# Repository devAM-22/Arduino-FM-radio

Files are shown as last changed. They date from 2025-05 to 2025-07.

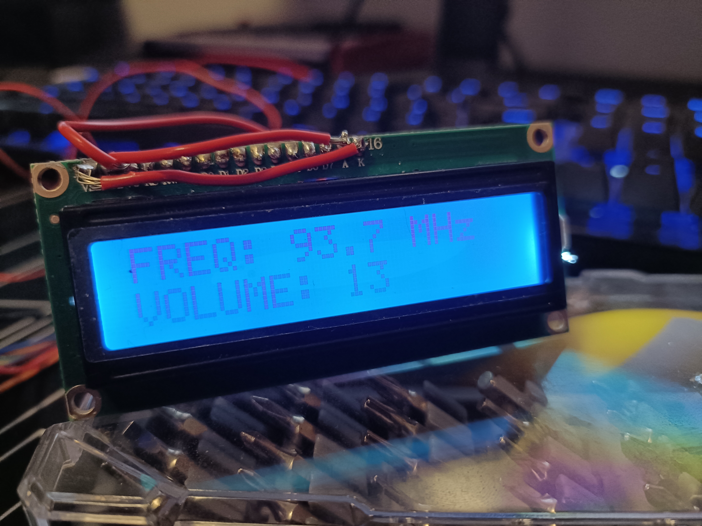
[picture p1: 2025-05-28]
Kuvat/IMG20250411095131.jpg

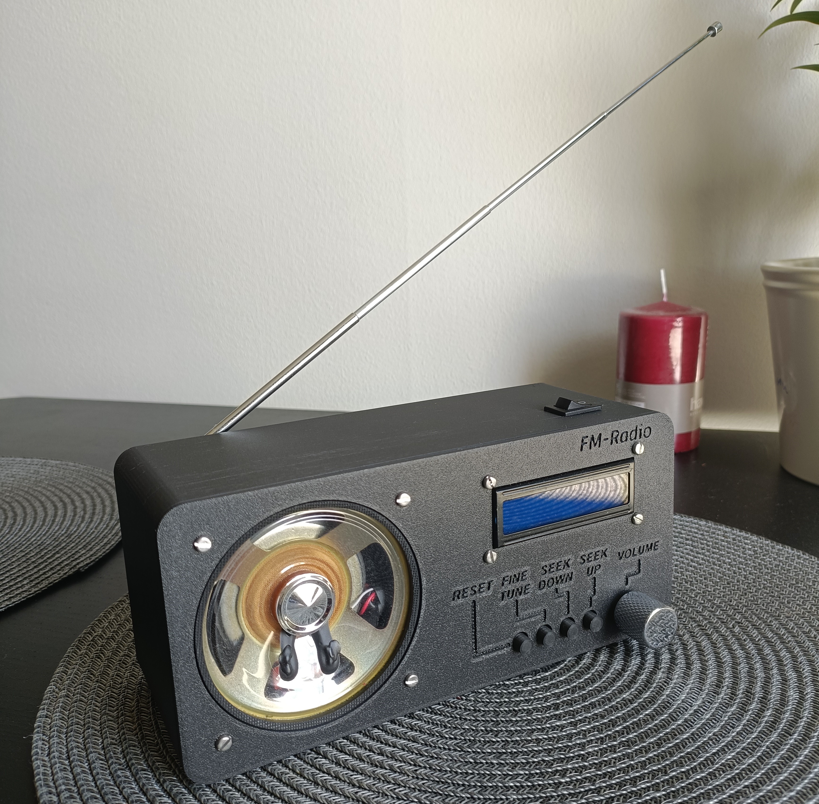
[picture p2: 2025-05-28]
Kuvat/IMG20250505140647.jpg

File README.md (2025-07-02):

\# Kandidaatintyö: Arduino-alustan hyödyntäminen elektroniikkalaitteen suunnittelussa

Tämä GitHub-repositorio sisältää kandidaatintyöni, jonka aiheena on Arduino-alustan hyödyntäminen elektroniikkalaitteen suunnittelussa. Työ on tehty osana Tampereen yliopiston tieto- ja sähkötekniikan kandidaattiohjelmaa, ja se on hyväksytty 22.5.2025.

---

\## 📁 Sisältö

\- `3D-tulostus/` – Sisältää 3D-mallin, jonka avulla laitteen kotelo on luotu  

\- `Kuvat/` – Sisältää kuvia laitteen rakentamisen eri työvaiheista  

\- `Ohjelma/` – Sisältää laitteeseen luodun pääohjelman sekä SparkFun Electronicsin Si4703\_breakout-kirjaston  

\- `Piirilevy/` – Sisältää Altium Designerilla luodut osasijoittelukuvat sekä piirilevyn valotusmaskin  

\- `Kandidaatintyö.pdf` – Valmis raportti  

\- `Lohkokaavio.png` – Lohkokaavio, joka esittää laitteen funktionaaliset lohkot  

\- `README.md` – Tämä tiedosto

---

\## 🛠️ Käytetyt teknologiat

\- Piirilevysuunnittelu: Altium Designer  

\- 3D-malli: Autodesk Fusion  

\- Ohjelmointi: Arduino IDE / C++  

\- Simulointi: LTSpice

---

\## 📨 Yhteystiedot

Aapo Manni  

📧 manni.aapo@gmail.com

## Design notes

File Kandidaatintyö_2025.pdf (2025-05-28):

## Aapo Manni

# ARDUINO-ALUSTAN HYÖDYNTÄMINEN ELEKTRONIIKKALAITTEEN SUUNNITTELUSSA

Kandidaatintyö
Informaatioteknologian ja viestinnän tiedekunta (ITC) Tarkastaja: Katja Laine
toukokuu 2025

i

## TIIVISTELMÄ

Aapo Manni: Arduino-alustan hyödyntäminen elektroniikkalaitteen suunnittelussa (Utilizing the Arduino platform in desinging of an electronic device)
Kandidaatintyö
Tampereen yliopisto
Tieto- ja sähkötekniikan kandidaattiohjelma
Toukokuu 2025

Arduinojen suosio elektroniikkalaitteiden rakentamisessa on saavuttanut suurta suosiota viimeisen kymmenen vuoden aikana. Syynä tälle suosiolle on niiden halpa hinta ja aloittelijaystävällisyys. Suosion kasvua on kiihdyttänyt myös niiden avoimen lähdekoodin saavutettavuus, jonka ansiosta Arduinon piirikaaviot, sekä muut resurssit ovat kaikkien saatavilla.
Tässä kandidaatintyössä suunnitellaan, simuloidaan ja rakennetaan Arduino-pohjainen FM-radio, joka hyödyntää mikrokontrollerinaan Arduinosta tuttua Atmega328p:tä. Samalla Arduinoa käytetään laitteen testaamiseen koekytkentälevyillä, sekä lopullisen kokoonpanon ohjelmointiin. Tässä työssä Arduinoa siis käytetään melkein jokaisessa suunnittelun vaiheessa.
Tämä työ pyrkii vastaamaan kysymykseen siitä, voiko Arduinolla itse rakentaa toimivan FM-radion. Samalla perehdytään siihen, miten Arduinoa voidaan hyödyntää elektroniikkalaitteen suunnittelun eri vaiheessa sekä siihen, että voiko itse tehdyllä radiolla rahallisesti kilpailla kaupallista tuotetta vastaan.
Rakennettu laite osoittautuu toimivaksi, mutta samalla sen toimintaa parantavia kehityskohteita on yhä havaittavissa. Lopulta päädytään tulokseen, että kaupallinen radio on käytännöllisempi ja kustannustehokkaampi valinta, mikäli käyttäjä tarvitsee yksinkertaisen vaihtoehdon radiotaajuuksien kuunteluun. FM-radiota itse suunniteltaessa on kuitenkin mahdollista vaikuttaa laajemmin luodun laitteen ominaisuuksiin. Lopuksi todetaan, että Arduino-alusta on tehokas ja edullinen tapa suunnitella elektroniikkalaitteita, koska sitä on mahdollista käyttää lähes jokaisessa suunnittelun vaiheessa aina prototyypin rakentamisesta mikrokontrollerin ohjelmointiin asti.

Avainsanat: Arduino, FM-radio, elektroniikkalaitteen suunnittelu, sulautettu järjestelmä, mikrokontrolleri, C++-ohjelmointi

Tämän julkaisun alkuperäisyys on tarkastettu Turnitin Originality Check -ohjelmalla.

ii

## TEKOÄLYN KÄYTTÖ OPINNÄYTTEESSÄ

Opinnäytteessäni on käytetty tekoälysovelluksia:

☐ Ei
☒ Kyllä

Ilmoitukseni mukaan olen käyttänyt opinnäytteessäni tutkielmaprosessin aikana seuraavia tekoälysovelluksia: ChatGPT, Andor Tekoälyavustaja

Tekoälysovellusten nimet ja versiot: GPT-4o, GPT-4, GPT-4o mini

Käyttötarkoitus: Osittainen käsitteiden suomennos, lauserakenteiden parannus, ohjelmakoodin syntaksin tarkistus sekä avustaminen lyhenneluettelon muodostamisessa. Lisäksi tiedonhaussa on käytetty Andorin Tekoälyavustajaa lähteiden etsintään.

Osiot, joissa tekoälyä on käytetty: Lyhenneluettelo, luvut 2 ja 3, lähteet ja liite D

Olen tietoinen siitä, että olen täysin vastuussa koko opinnäytteeni sisällöstä, mukaan lukien osat, joissa on hyödynnetty tekoälyä, ja hyväksyn vastuun mahdollisista eettisten ohjeiden rikkomuksista.

iii

## SISÄLLYSLUETTELO

iv

## LYHENTEET JA MERKINNÄT

3D | engl. Three-dimensional, kolmiulotteinen
AC | engl. Alternating Current, vaihtovirta
ACK | engl. Acknowledgement, tiedonsiirron vahvistus
ADC | engl. Analog to Digital Conversion, analogisen signaalin
| muuntaminen digitaaliseksi
AVR | engl. Alf and Vegard’s RISC processor, Atmelin
| mikrokontrolleriarkkitehtuuri
BOD | engl. Brown-Out Detector, jännitteen alaraja,
| jolla mikrokontrolleri resetoituu
C++ | Ohjelmointikieli
DC | engl. Direct Current, tasavirta
DIP28 | engl. Dual In-line Package, 28-pinninen kotelointi
FM | engl. Frequency Modulation, taajuusmodulaatio
GPIO | engl. General Purpose Input/Output, yleiskäyttöiset tulo-/lähtöpinnit
I2C | engl. Inter-Integrated Circuit, sarjamuotoinen
| tietoliikenneväylä mikropiirien välillä
IC | engl. Integrated Circuit, integroitu piiri
IDE | engl. Integrated Development Environment,
| integroitu kehitysympäristö
ISP | engl. In-System Programming, mikrokontrollerin
| ohjelmointi sen ollessa osa valmista piiriä
LCD | engl. Liquid Crystal Display, nestekidenäyttö
MPX | engl. Stereo Multiplexing, stereon ja monon
| yhdistäminen FM-signaalissa
PCB | engl. Printed Circuit Board, piirilevy
ppm | engl. Parts Per Million, miljoonasosa
RC | engl. Resistor-Capacitor, vastuksesta ja kondensaattorista
| koostuva oskillaattori
RDS | engl. Radio Data System, radiotietojärjestelmä
RST | engl. Reset, resetointipinni
R/W | engl. Read/Write, lukeminen/kirjoittaminen tiedonsiirrossa
SCL | engl. Serial Clock, kellosignaali
SDA | engl. Serial Data, sarjadata
SEN | engl. Serial Enable, kolmijohtoyhteyden käyttömahdollisuus
C | kapasitanssi
dB | desibeli
f−3dB | -3 dB-rajataajuus, taajuus, jossa amplitudi on laskenut kolme desibeliä
Hz | hertsi, taajuuden yksikkö
IG | maajohtimen virta
Iin | tulovirta
IL | kuormavirta

v

kHz | kilohertsi, taajuuden yksikkö
kΩ | kilo-ohmi, resistanssin yksikkö
mA | milliampeeri, virran yksikkö
MHz | megahertsi, taajuuden yksikkö
mil | piirilevysuunnittelussa käytetty mittayksikkö, 0,0254 mm
mm | millimetri
nH | nanohenry, induktanssin yksikkö
PD | regulaattorin tehohäviö
R | resistanssi
Vin | tulojännite
Vout | lähtöjännite
W | watti, tehon yksikkö
µF | mikrofaradi, kapasitanssin yksikkö

## 1. JOHDANTO

Ostettuani Arduino-aloituspakkauksen elektroniikkaharrastustani varten, havahduin poh-

timaan, mitä kaikkea kyseisellä pakkauksella voisi luoda. Olen vuosien ajan ollut äärim-

mäisen kiinnostunut langattomasta tiedonsiirrosta ja etenkin FM-radioista, mikä herätti

kysymyksen siitä, voiko Arduinon kaltaisella laitteella luoda itse kotiolossa toimivan FM-

radion. Runsaan internetin selaamisen jälkeen löysin Arduinoon kytkettävän kehitysalus-

tan, joka mahdollistaisi sen muuttamisen FM-radioksi. Päädyin lopulta ostamaan tämän

kehitysalustan, jonka jälkeen aloin toteuttamaan ensimmäistä alusta loppuun suunnitte-

lemaani elektroniikkalaitetta.

Tässä työssä suunnitellaan ja toteutetaan Arduino-pohjainen FM-radio prototyyppita-

solta valmiiksi laitteeksi asti. Luvussa 2 esitellään projektin osat yksitellen ja niiden mer-

kitystä laitteen toiminnan kannalta avataan tarkemmin. Lisäksi tässä luvussa määritel-

lään muutamia laskukaavoja, joita käytetään työn muissa vaiheissa.

Luvussa 3 siirrytään käsittelemään suunnittelun vaiheita laitteen ominaisuuksien määrit-

telystä aina viimeistellyn kotelon luontiin. Lisäksi kolmannessa luvussa testataan suun-

niteltuja lohkoja simulaatioiden avulla. Simulaatioiden jälkeen siirrytään kirjoittamaan lait-

teen ohjelmistoa, joka lopulta testataan koekytkentälevyjen avulla. Onnistuneiden tes-

tausten jälkeen suunnitellaan laitteelle piirilevy sekä ohjelmoidaan työhön tuleva mikro-

kontrolleri käyttäen Arduinoa ohjelmointityökaluna. Lopulta työ päätetään rakentamalla

3D-tulostettu kotelo laitteen elektroniikkaosien suojaksi.

FM-radio on keksintönä hyvin vanha ja monelle varsin arkinen laite. Radioita on markki-

noilla nykyään suuri määrä ja niiden ominaisuudet vaihtelevat erittäin paljon. Tämän työn

tavoitteena on vastata kysymykseen siitä, voiko itse suunniteltu radio vastata kaupasta

ostettavaa laitetta. Samalla pyritään Arduino-alustaa käyttämään mahdollisimman mo-

nessa suunnittelun vaiheessa.

## 2. PROJEKTIN OSIEN ESITTELY

Ennen projektin aloittamista on tärkeää käydä läpi sen funktionaaliset lohkot. Elektroniik-

kalaitteen suunnittelussa kannattaa laitteen osiin suhtautua itsenäisinä lohkoinaan, jol-

loin suunnittelu on helpompi jakaa osiin. Tässä kappaleessa esitetään viimeistellyn lait-

teen rakentamiseen tarvitut osat, sekä perehdytään teoriatasolla niiden merkitykseen

laitteen toiminnan kannalta.

### 2.1 Arduino

Arduino on avoimen lähdekoodin elektroniikka-alusta, mikä mahdollistaa yksinkertaisten

ja jossain tapauksessa monimutkaistenkin elektroniikkalaitteiden suunnittelun ja toteu-

tuksen. Arduino-alusta on saavuttanut suurta suosiota varsinkin opetuskäytössä sen yk-

sinkertaisuuden ja aloittelijaystävällisen käyttöliittymän vuoksi. [1] Samalla Arduino kui-

tenkin tarjoaa paljon mahdollisuuksia kokeneemmallekin elektroniikkaharrastajalle, joka

tarvitsee alustaa esimerkiksi nopean prototyypin rakentamiseen. Arduinon suurta suo-

siota on lisännyt myös se, että siihen on saatavilla suuri määrä moduuleita ja lisäosia,

joiden avulla Arduinosta itsestään on mahdollista toteuttaa esimerkiksi lämpömittari.

Näitä moduuleita ja lisäosia on mahdollista käyttää monenlaisten laitteiden prototyyppien

rakentamiseen, minkä ansiosta monet rakentavakin Arduinon ja koekytkentälevyn avulla

elektroniikkalaitteen prototyyppiversion ja siihen kuuluvan mikrokontrolleriohjelmiston

ennen varsinaisen laitteen valmistusta. Jossain tapauksessa Arduino saatetaan jopa jät-

tää osaksi viimeisteltyä laitetta.

Arduinosta on olemassa monia erilaisia malleja ja valmistajia, mutta yleisesti Arduinolla

kuitenkin viitataan Atmelin megaAVR-pohjaisen mikrokontrollerin omaaviin järjestelmiin

[2, s.77]. Pohjimmiltaan Arduino on niin kutsuttu sovituslevy (breakout board) AVR-mik-

rokontrollerille. Tämän sovituslevyn päätehtävä on luoda kiinteä pakkaus, joka helpottaa

mikrokontrollerin testausta sekä pääsyä sen eri pinneille tilanteessa, jossa komponentti

on ns. pintaliitoskomponentti [3]. Sovituslevyt ovat erittäin tärkeitä varsinkin koekytken-

tälevyllä tehtävässä testauksessa, koska pintaliitoskomponentteja ei suoraan ole mah-

dollista kytkeä koekytkentälevyn reikiin.

Useassa tilanteessa kuten tässäkin työssä, Arduinoa käytetään laitteen ensimmäisen

prototyypin rakentamiseen koekytkentälevylle ennen kuin tämä suunnitelma siirretään

PCB-levylle (Printed Circuit Board). Tämä onnistuu kopioimalla kuvassa 1 esitetty Ardui-

non arkkitehtuuri PCB-levylle käyttäen mikrokontrolleria ja siihen kytkettyjä oheislaitteita,

joista merkittävimpänä on kvartsikide, joka toimii ulkoisena kellosignaalilähteenä. Ar-

duinolla suunniteltu järjestelmä voidaan tällöin suoraan siirtää PCB-levylle.

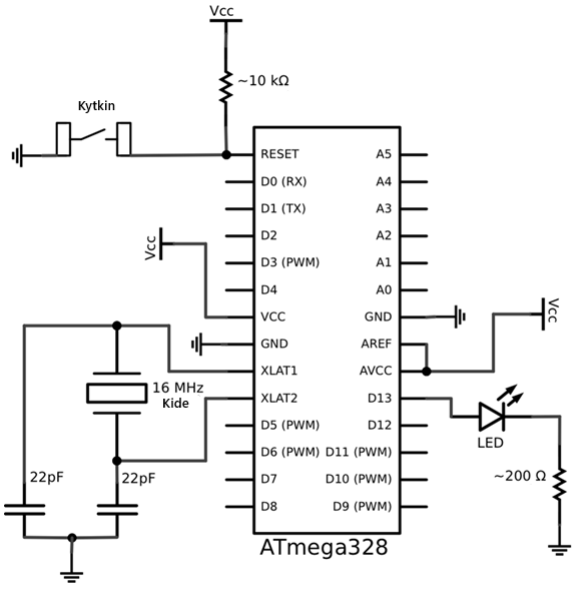
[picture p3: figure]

Kuva 1. Arduino Unon arkkitehtuuri DIP28-koteloinnille [mukaillen lähteestä 4].

Keskeinen osa sulautettua järjestelmää on sen ohjelmiston suunnittelu. Arduinon ta-

pauksessa ohjelmointi tapahtuu yleisesti Arduino IDE:n avulla. Arduino IDE on avoimen

lähdekoodin maksuton ohjelmointi- ja kehitysympäristö, joka on kehitetty juuri Arduinojen

ohjelmoimiseen [5]. Harjaantuneemmat käyttäjät siirtyvätkin useasti käyttämään kehitty-

neempiä ohjelmistoympäristöjä, kuten esimerkiksi Microchip Studiota, mitkä mahdollis-

tavat mikrokontrollerien rekisterien tarkemman tarkastelun ja monia muita kehittyneem-

piä ohjelmistotyökaluja. Arduino IDE:llä on kuitenkin omanlaisiaan etuja, joita esimerkiksi

Microchip Studiossa ei ole. Arduino IDE:n edut keskittyvät nimenomaan sen yksinkertai-

suuteen ja aloittelijaystävällisyyteen.

Käytännön ohjelmointi Arduinolla tapahtuu perinteisellä C++-ohjelmointikielellä, kuten

monissa muissakin ohjelmointiympäristöissä, mutta se kuitenkin sisältää funktioita ja ra-

kenteita, jotka yksinkertaistavat ja lyhentävät kirjoitettavaa syntaksia. Hyvänä esimerk-

kinä tällaisesta yksinkertaistuksesta on tämänkin työn kannalta tärkeä Analog to Digital

Conversion eli ADC-muunnos. ADC-muunnosta käytetään tässä työssä äänenvoimak-

kuuden lukemiseen potentiometrin jännitearvosta. Atmega328p:n datalehden mukaisesti

ADC-muunnos vaatii useita toimenpiteitä, kuten oikean ADC-kanavan valinta, ADC-

muunnoksen käyttöönotto, mahdollinen keskeytyskäsittelijä, esijakaja sekä itse muun-

noksen käynnistys [6, s. 205-220]. Arduino IDE:ssä tämä vaihe on kuitenkin luotu yh-

deksi yksinkertaiseksi funktioksi nimeltään ANALOG_READ(), jota kutsumalla Arduino

lukee parametrina annetun analogipinnin arvon ja muuntaa sen digitaaliseksi arvoksi.

Halutessaan käyttäjä voi kuitenkin kirjoittaa ohjelman käyttäen puhdasta C++-kieltä

edellä mainittujen vaiheiden mukaisesti, mutta omien funktioidensa avulla Arduino IDE

helpottaa aloittelijoiden tutustumista ohjelmointiin.

Toinen aloittelijoille suunnattu ominaisuus, jonka Arduino IDE sisältää, on sen sisäänra-

kennetut ohjelmointikirjastot. Tällaisia kirjastoja ovat esimerkiksi tässäkin työssä käytet-

tävä LiquidCrystal-kirjasto. Tämä kirjasto on suunnattu LCD-näyttöjä (Liquid Crystal

Display) varten ja se luo helpon ja yksinkertaisen tavan esittää erilaisia tietoja ohjelman

toiminnasta. Useassa tapauksessa nämä kirjastotkin on koodattu mahdollisimman käyt-

täjäystävällisiksi, siten että esimerkiksi juuri LiquidCrystal-kirjaston osalta käyttäjän tar-

vitsee vain alustaa ne Arduinon pinnit, joihin LCD-näyttö on kiinnitetty. Tämän jälkeen

käyttäjän tarvitsee vain kutsua jotain kirjaston funktiota sen enempää miettimättä, mitä

LCD-näytön toimiessa oikeastaan edes tapahtuu. Lisäksi Arduinon suuren suosion an-

siosta internetistä löytyy paljon muiden käyttäjien ja yritysten luomia kirjastoja juuri tie-

tyille Arduino-malleille, mitkä tekevät ulkoisten moduulien ja lisälaitteiden lisäämisen

vielä entistäkin helpommaksi. Tässä työssä käytettävä Si4703-kehitysalusta hyödyntää

juuri tämän tapaista kirjastoa.

Arduino on avoimen lähdekoodin sovellus, joten siitä on saatavilla kaikki tarvittavat tiedot

aina lähdekoodista piirikaavioihin asti. Tämän avoimuuden ansiosta kuka tahansa voi

siis rakentaa oman Arduinonsa, mikä on suurin syy sille, että Arduino-klooneja on saa-

tavilla runsaasti [7, luku 1]. Tässä työssä on ohjelmiston ja elektroniikkapuolen suunnit-

teluun käytetty Crowduino UNO v. 1.1:stä, joka on esitetty alla olevassa kuvassa 2. Ky-

seessä on siis Arduino UNOa vastaava klooni.

Joissakin klooneissa ominaisuudet eroavat alkuperäisestä Arduino-mallista hyvinkin pal-

jon. Tässäkin tapauksessa Crowduino UNO sisältää paljon ominaisuuksia, joita perintei-

sestä Arduino UNOsta ei löydy. Tärkein tällainen ominaisuus tämän työn kannalta on

säädettävä logiikkataso. Tämä siitä syystä, että Si4703-kehitysalusta, joka mahdollistaa

radion toiminnan, käyttää 3,3 V:n jännite- ja logiikkatasoja [8]. Perinteisessä Arduino

UNOssa käyttöjännite ja logiikkataso on asetettu olemaan aina 5 V, mikä kuitenkin pa-

himmassa tapauksessa tuhoaisi Si4703-kehitysalustan.

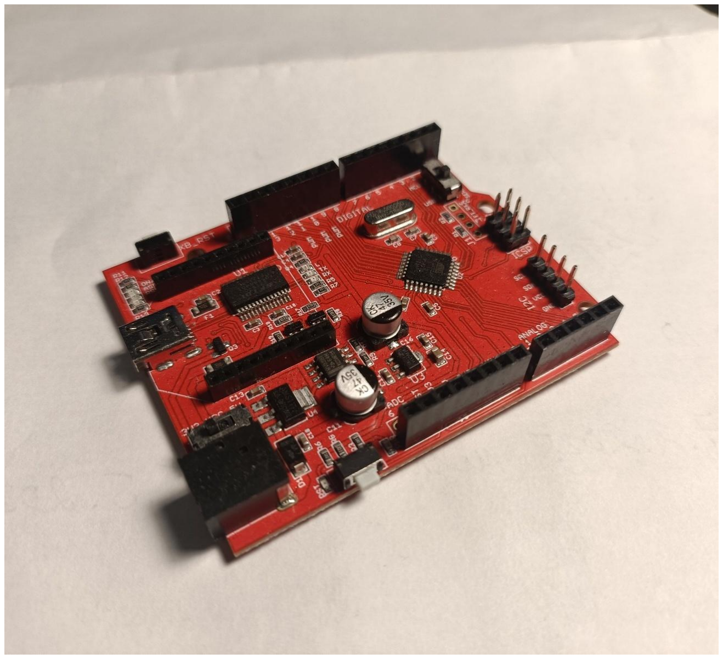
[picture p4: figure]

Kuva 2. Crowduino v1.1.

Tilanteissa, jossa Arduinolla kehitetty projekti halutaan siirtää käytännön toteutukseen

piirilevylle, tulee ottaa huomioon muutamia asioita. Näistä keskeisimpiä on käyttöjännite

ja käytetty kellotaajuus. Datalehtensä mukaisesti Atmega328p-mikrokontrolleri voi ope-

roida 2,7–5,5 V käyttöjännitteellä ja kellotaajuus voi olla välillä 0-16 MHz [6, s. 2]. At-

mega328p:n tapauksessa kellolähteeksi voidaan valita joko ulkoinen tai sisäinen kellolähde. Perinteisessä Arduino UNOssa käytetään ulkoisena kellolähteenä 16 MHz kvart-

sikidettä [4], mutta Atmega328p tarjoaa myös mahdollisuuden sisäisen RC-oskillaattorin

käyttöön kellolähteenä. RC-oskillaattoreita on Atmega328p:n tapauksessa kaksi eri-

laista, 8 MHz ja 128 kHz [6, s. 25], mitkä on mahdollista jakaa vielä pienempiin arvoihin

esijakajan avulla.

Mikäli siirtymisen Arduinolta piirilevylle haluaa tehdä mahdollisimman suoraviivaisesti,

kannattaa Arduinon arkkitehtuuri kopioida suoraan suunniteltuun laitteeseen. Toisin sa-

noen, jos projektin kehityksessä on käytetty Arduino UNOa, joka operoi 5 V:n käyttöjän-

nitteellä ja 16 MHz kellotaajuudella, kannattaa tämä arkkitehtuuri kopioida lopulliseen

kokoonpanoon, jotta siirtyminen on mahdollisimman suoraviivainen. Tämän projektin

osalta tämä siirtymä ei kuitenkaan ollut näin suoraviivainen johtuen siitä, että järjestel-

män käyttöjännite tulee olla 3,3 V. Si4703-kehitysalustan asennusohjeessa neuvotaan

käyttämään Arduino UNOn sijasta Arduino Pro Miniä järjestelmän mikrokontrollerina, jol-

loin tarvetta logiikkatasomuuntimelle ei ole [8]. Arduino UNO ja Pro Mini molemmat käyt-

tävät Atmega328p:tä mikrokontrollerinaan, mutta suurin ero niiden välillä syntyy siitä,

että Pro Mini on saatavilla myös 3,3 V:n ja 8 MHz versiona [9]. Tässä työssä Arduinon

arkkitehtuuri on siis itse asiassa kopioitu Arduino Pro Ministä, vaikka itse laitteen testaus

koekytkentälevyllä on tehty käyttäen Arduino UNOn kloonia.

Lopullisessa kokoonpanossa Atmega328p operoi siis käyttäen 3,3 V:n käyttöjännitettä.

Tämä jännitearvo asettuu hyvin datalehden mukaiseen 2,7-5,5 V:n käyttöjännitteeseen.

[6, s. 2] Kellolähteen määrittämiseen taas on useampia mahdollisuuksia. Kellolähde

määrittää siis jaksonajan, jolla mikrokontrolleri operoi. Datalehdellä esitetyn kuvaajan

(kuva 3) mukaisesti voidaan määrittää käyttöjännite ja kellotaajuus, jolla Atmega328p

operoi luotettavasti [6, s. 260]. Kuvan 3 mukaisesti 3,3 V:n käyttöjännitteellä 8 MHz kel-

lotaajuus mahdollistaa luotettavan toiminnan. Vastaavasti Arduino UNOn käyttämä kel-

lotaajuus eli 16 MHz olisi taas liian suuri käytettyyn käyttöjännitteeseen verrattuna, jolloin

mikrokontrolleri ei toimisi enää luotettavasti turvallisen käyttöalueen sisällä.

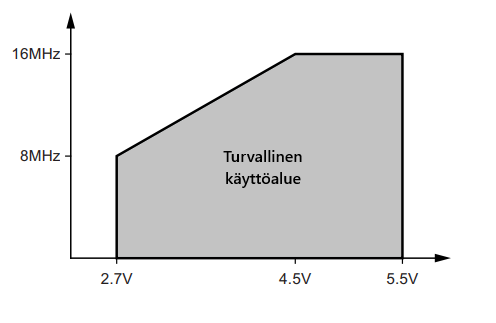
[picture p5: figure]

Kuva 3. Kellotaajuuden suuruus käyttöjännitteen funktiona [mukaillen lähteestä 6].

Edellisten päätelmien mukaisesti 8 MHz näyttäisi olevan hyvä valinta kellolähteen luo-

miseen 3,3 V:n käyttöjännitteellä. Vielä tulee kuitenkin valita, tuleeko lopullisessa projek-

tissa käyttöön ulkoinen 8 MHz kellolähde vai Atmega328p:n oma sisäinen 8 MHz oskil-

laattori. Tämän työn osalta on päädytty käyttämään ulkoista 8 MHz kvartsikidettä, koska

yleisesti niitä pidetään luotettavampina ja niiden tarkkuus on parempi kuin sisäisen os-

killaattorin. Tähän syynä on se, että ulkoisen kellolähteen, eli tässä tilanteessa kvartsi-

kiteen lupaama virhetoleranssi on ±30 ppm (Parts per million) [10]. Toisin sanoen virhettä

voi 8 MHz taajuudella syntyä maksimissaan ±240 Hz. Vastaavasti Atmega328p:n data-

lehdellä on ilmoitettu RC-oskillaattorin tarkkuudeksi huoneenlämmössä 3 V:n käyttöjän-

nitteellä ±2 % [6, s. 260]. Jos tämä arvo muunnettaisiin edelliseen tapaan taajuusarvoksi,

vastaisi se virhetoleranssia ±160 kHz. Näiden päätelmien avulla voidaan todeta, että

kvartsikiteen lisääminen kellolähteeksi on erittäin järkevää, sillä sen avulla voidaan vir-

hetoleranssia laskea moninkertaisesti. Mikrokontrollerin kellosignaalin tarkkuus tässä ti-

lanteessa on äärimmäisen tärkeä osa-alue, koska mikrokontrolleri kommunikoi Si4703-

kehitysalustan kanssa käyttäen I2C-datalinjaa (Inter-Intergrated Circuit). Ilman kunnol-

lista kellosignaalia tiedonsiirto ei onnistu tai pahimmassa tapauksessa se on virheellistä.

### 2.2 Si4703 FM-tuner

Si4703 on FM-vastaanotin IC (Integrated Circuit) erilaisiin kannettaviin sovelluksiin, ku-

ten MP3-soittimiin ja kannettaviin radioihin [11, s.1]. Tässä työssä ei kuitenkaan suora-

naisesti käytetä Si4703 IC:tä, vaan SparkFun Electronicsin valmistamaa kuvan 4 mukaista Si4703-kehitysalustaa, joka on Arduinon lailla sovituslevy Si4703 IC:lle. Tästä ke-

hitysalustasta on olemassa kahta erilaista mallia, joista toinen sisältää oman audiovah-

vistimensa ja toinen ei. Tässä työssä käytetty malli on ensimmäisenä mainittu eli se siis

sisältää jo itsessään oman audiovahvistimensa. Tämä malli on valikoitu tähän työhön

myös sen vuoksi, että se sisältää valmiiksi 3.5 mm audioliittimen, joka helpottaa laitteen

suunnittelua ja testausta koekytkentälevyllä. Tämä audioliitin mahdollistaa sen, että ke-

hitysalustaan on mahdollista kytkeä esimerkiksi nappikuulokkeet, joiden kautta voi suo-

raan kuunnella radioasemia. Käytännössä kehitysalusta hoitaa vastaanotetun FM-sig-

naalin demoduloinnin ja vahvistamisen, mutta se ei itsessään sisällä minkäänlaisia oh-

jaimia. Kehitysalustan ohjaaminen toteutetaan käyttäen I2C-sarjaliikennettä, mikä tässä

tilanteessa tehdään mikrokontrollerin avulla.

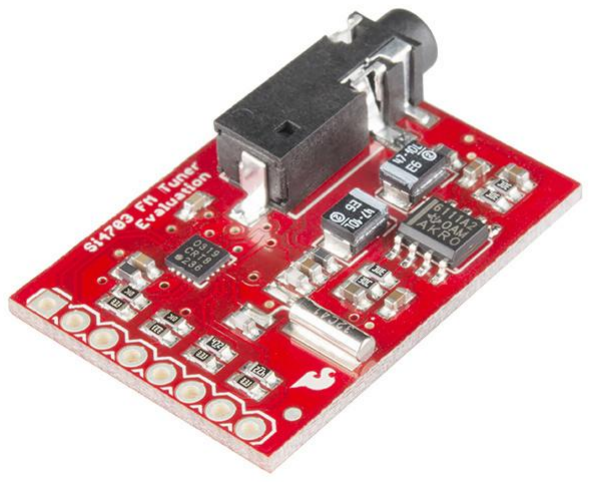
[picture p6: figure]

Kuva 4. Si4703-kehitysalusta [8].

I2C on alun perin Philipsin kehittämä sarjaliikenneprotokolla, joka on tarkoitettu mikro-

prosessorien ja niihin kytkettyjen oheislaitteiden väliseen kommunikointiin. I2C-väylä

koostuu kahdesta kaksisuuntaisesta tietolinjasta eli sarjadatalinjasta (Serial Data) ja kel-

losignaalista (Serial Clock), jotka on yhdistetty isäntälaitteen (master) ja orjalaitteen

(slave) välille. [12, s. 169] Useimmissa tilanteissa isäntälaitteena toimii juuri mikrokont-

rolleri ja orjalaitteena oheislaite, jota halutaan ohjata tai josta halutaan vastaanottaa tie-

toa. Yhteen isäntälaitteeseen on mahdollista lisätä useampi kuin yksi orjalaite kerrallaan,

koska jokaisella I2C-orjalaitteella on oma uniikki laiteosoitteensa. Tässä työssä At-

mega328p toimii I2C-väylän isäntälaitteena ja Si4703-kehitysalusta orjalaitteena.

I2C-tiedonsiirron alustuksessa isäntälaite pyrkii ottamaan yhteyden orjalaitteeseen lä-

hettämällä datalinjaan orjalaitteen laiteosoitetta ja sen perässä R/W-bittiä (read/write),

eli tietoa siitä haluaako isäntä lukea vai kirjoittaa dataa orjalaitteeseen. Mikäli laiteosoi-

tetta vastaava orjalaite löytyy, vastaa orjalaite isäntälaitteelle ACK-bitin avulla (Acknow-

ledge), jonka jälkeen itse tiedonsiirto voi alkaa. [12, s.169] Datasiirron alkaessa data

isännän ja orjan välillä alkaa siirtymään 8 bitin kehyksessä riippuen yhteyden alussa

määritetystä R/W-bitin arvosta, jonka jälkeen kehys lopetetaan orjan lähettämällä ACK-

bitillä [2, s. 95]. Mikäli R/W-bitin arvo oli yhteyden alustuksen aikana yksi, tarkoittaa tämä

sitä, että isäntä haluaa lukea dataa orjalaitteesta. Vastaavasti, jos R/W-bitti oli yhteyden

alussa nolla, haluaa isäntälaite kirjoittaa dataa orjalaitteeseen. Keskeistä I2C-kommuni-

koinissa on se, että se on toteutettu noudattamaan ns. active low-periaatetta, jolloin sig-

naalin arvo on aina korkealla, ellei sitä erikseen vedetä alas ulkoisen vastuksen avulla

arvoksi nolla. Tämä johtuu siitä, että laitteiden konfiguroinnissa on käytetty avokollekto-

ritransistoreja, jotka johtavassa tilassa vetävät datalinjan nollaan imaistessaan virtaa ul-

koisen vastuksen läpi [2, s.94-95].

Si4703-kehitysalusta sisältää käyttöjännite- ja I2C-pinnien lisäksi myös muita pinnejä

useita eri käyttötarkoituksia varten. Tällaisia pinnejä ovat SEN, RST, GPIO1 ja GPIO2.

SEN-pinni on otettu kehitysalustaan omaksi pinnikseen, sillä se mahdollistaa kommuni-

koinnin laitteen kanssa I2C:n lisäksi käyttäen kolmijohtoyhteyttä (3-Wire) [8]. Kolmijoh-

toyhteys tarkoittaa siis kokonaan eri kommunikointimenetelmää kuin I2C, koska siinä

kommunikointiin käytetään kahden johtimen sijasta kolmea. RST-pinni on nimensä mu-

kaisesti varattu kehitysalustan resetointia varten [8]. Tämän työn osalta RST-pinni on

kytketty Atmega328p:n pinniin PD2. Tämä siitä syystä, että RST-pinnillä on merkitys ke-

hitysalustan käynnistyksessä, koska sen avulla kehitysalusta asetetaan toimimaan käyt-

täen I2C-tiedonsiirtoa kolmijohtoyhteyden sijasta [11, s.19]. Erona tässä SEN-pinniin on

se, että RST-pinnin tilaa tulee vaihtaa alustuksen aikana korkean (1) ja matalan tilan (0)

välillä. SEN-pinnin kohdalla riittää johtoyhteyden valintaan joko korkea tai matala tila.

Tässä tilanteessa kehitysalustaan on lisätty valmiiksi 10 kΩ ylösvetovastus, mikä mah-

dollistaa sen [8], että SEN-pinnin signaali on vakiona aina korkea. Tästä seuraa se, että

SEN-pinniin ei tarvitse kytkeä johdinta, mikäli käyttöön halutaan ottaa I2C-kommuni-

kointi. Kehitysalustan kaksi viimeistä pinniä GPIO1 ja GPIO2 ovat yleiskäyttöisiä tulo- ja

lähtöpinnejä (General Input/Output pins), joita voidaan käyttää useaan eri tarkoitukseen

[8]. Yleisesti näitä kahta pinniä voidaan käyttää indikaattorina siitä, että onko RDS-data

(Radio Data System) valmista luettavaksi tai onko kuunneltu kanava stereo- vai mono-

kanava [11, s.16].

Eräs syy siihen, miksi juuri Si4703-kehitysalusta on valittu tähän työhön, on se, että siitä

on saatavilla valmiina oleva Arduino-kirjasto, mikä helpottaa vastaanottimen ohjaamista

huomattavasti. Toisin sanoen tämä kirjasto sisältää valmiit komennot, joilla kehitysalus-

taa ohjataan. Tämän kirjaston takana on sama tuotantoryhmä, joka on suunnitellut

Si4703-kehitysalustan eli SparkFun Electronics [13]. Arduino-kirjasto helpottaa laitteen

ohjelmointia suuresti, koska ohjelmiston puolesta suurin työ on tehty jo valmiiksi. Jos

kuitenkin kirjaston sisältöä haluaa muokata tai luoda kokonaan oman Arduino-kirjas-

tonsa Si4703:n hallintaan, on sekin täysin mahdollista. Si4703-datalehdellä on esitetty

kaikki toimenpiteet ja niitä koskevat rekisterit, joita muokkaamalla voi muokata IC:n toi-

mintaa. Tämän työn osalta Si4703-kirjasto on jätetty melko koskemattomaksi yhtä rekis-

teriä lukuun ottamatta. Tästä muutoksesta lisää luvussa 3.3.

Koska Si4703 IC on suunniteltu kannettaviin sovelluskohteisiin, on sen eräs erikoisuus

se, että se ei tarvitse ulkoista antennia vaan antennin virkaa hoitaa ulkoinen kuulokelii-

täntä. Tässä ongelmaksi muodostuu kuitenkin se, että Si4703 IC ei sisällä suoraa val-

miutta ulkoisen antennin yhdistämiseen. [14, s. 1] Koska Si4703 käyttää pääsääntöisesti

kuulokejohtoa ulkoisena antennina, on kehitysalustaan kytketty sitä varten kaksi lisä-

komponenttia, jotka mahdollistavat FM-taajuusalueen parhaan mahdollisen kuulumisen.

Näitä ovat kuvan 5 mukaisesti 270 nH käämi sekä AC-kytkentä, joka on toteutettu käyt-

täen 1 nF kondensaattoria [15]. AC-kytkennän tarkoitus on suodattaa vastaanotetusta

radiosignaalista DC-komponentti (DC-offset) [14, s. 19]. Vastaanotetun radiosignaalin

tulisi olla mahdollisimman puhdas AC-signaali, koska DC-komponentit aiheuttavat lait-

teen toimintaa haittaavia vääristymiä. Kondensaattorin lisäksi kytkennässä on 270 nH

käämi, joka pyrkii maksimoimaan jännitevahvistuksen koko FM-taajuusalueella [14,

s.19].

Kuvan 5 mukaisen käämin L1 ja kondensaattorin C5 arvo on määritetty käytettäväksi

silloin, kun antennina käytetään kuulokejohtoa. Tässä työssä tilanne on kuitenkin erilai-

nen, koska antennin tehtävää hoitaa ulkoinen piiska-antenni. Tällöin piiska-antennin koh-

dalla olisi käämin L1 ja kondensaattorin C5 arvot pitänyt määrittää uudelleen, jotta vas-

taanotettu signaali olisi ollut laadultaan paras mahdollinen. Tämän työn osalta arvojen

uudelleenmääritys on jätetty tekemättä, koska käytännön testauksen perusteella päästiin

kuuluvuuden osalta hyviin tuloksiin kytkemällä piiska-antenni suoraan kuulokeliitäntään

alla olevan kuvan 5 mukaisesti. Piiska-antenni on kytketty siis suoraan 3.5 mm audioliit-

timen maajohtimeen.

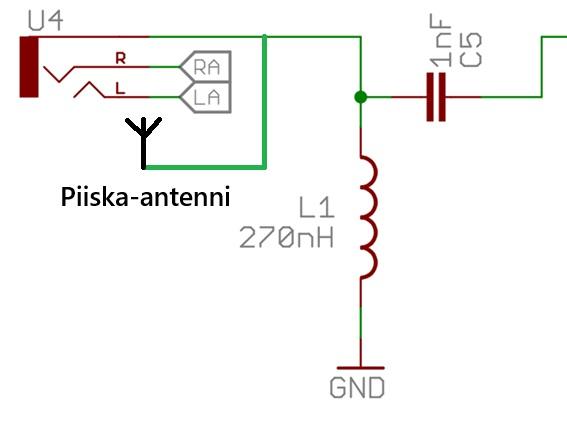
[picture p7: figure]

Kuva 5. Antenni ja sen lisäkomponentit [mukaillen lähteestä 15].

Si4703 IC:n mielenkiintoinen ominaisuus on se, että siihen on luotu valmius RDS-datan

prosessointiin. RDS on lyhenne sanoista Radio Data System, joka nimensä mukaisesti

tarjoaa mahdollisuuden radioaseman datan prosessointiin. Radioasemien lähettämä

data sisältää esimerkiksi tiedot siitä, mikä on toistettavan aseman tai soitettavan kappa-

leen nimi. [11, s.15] Tämän työn osalta RDS-datan prosessointi on jätetty pois käsitte-

lystä aihealueen rajaamiseksi. Laiteeseen on kuitenkin sisällytetty valmius RDS-datan

prosessointiin ja näin se olisi mahdollista lisätä osaksi laitetta tulevaisuudessa tekemällä

muutoksia ohjelmistoon.

### 2.3 LCD-näyttö

Radion toiminnan kannalta on äärimmäisen tärkeää, että käyttäjä saa jonkinlaista infor-

maatiota siitä, mitä kehitysalusta ja mikrokontrolleri ovat suorittamassa. Tällaista tietoa

on esimerkiksi soitossa oleva FM-taajuus sekä kanavan äänenvoimakkuus. Näiden tie-

tojen näyttämiseen tarvitaan siis jonkinlainen näyttö. Tässä työssä tähän tehtävään on

valittu LCD-näyttö.

LCD:n toiminta perustuu nimensä mukaisesti nestekiteisiin (liquid crystal), jotka on sul-

jettu kahden polarisoivan levyn väliin. Keskeistä kahdessa polarisoivassa levyssä on se,

että ne on sijoitettu 90° kulmaan toisiinsa nähden, jolloin valo voi polarisoitua vain näiden

kahden levyn polarisaatiosuunnan mukaisesti. [16, s. 43] Polarisoimattoman valon kom-

ponenteista pääsevät siis läpi vain ne, jotka ovat yhdensuuntaisia polarisoivien levyjen kanssa. Valon polarisointi mahdollistaa sen, että kun nestekidetason yli kytketään jän-

nite, kääntyvät nestekiteet sähkökentän suuntaisesti, jolloin polarisoitu valo ei pääse läpi

toisesta polarisoivasta levystä [16, s. 44]. Tällöin kyseinen pikseli esiintyy pimeänä. Vas-

taavasti, jos jännite kytketään pois päältä, pystyvät nestekiteet liikkumaan vapaasti, jol-

loin taustavalolta saapuva valo pääsee etenemään molempien polarisoivien levyjen läpi.

Tällöin kyseinen pikseli kytkeytyy päälle. Näin ollen jokaisen pikselin päällä oloa voidaan

kontrolloida yksinkertaisesti kytkemällä jännite nestekidetasoon. Ohjaamalla yksittäisiä

pikseleitä ja niiden joukkoja, voidaan muodostaa merkkejä sekä numeroita. Edellä ku-

vattu LCD-pikselin toiminta on havainnollistettu alla olevassa kuvassa 6.

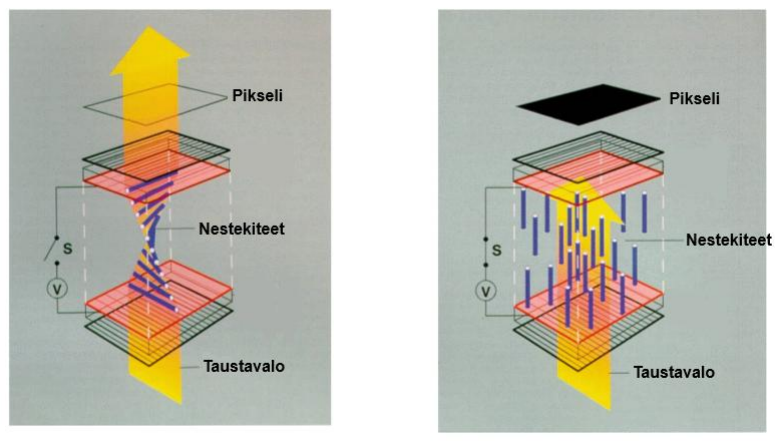
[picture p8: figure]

Kuva 6. Yksittäisen LCD-pikselin toiminta. Vasemmalla esitetty tilanne, jossa pik-

seli on päällä ja oikealla tilanne, jossa pikseli on kiinni [mukaillen lähteestä 17].

Pikseleiden ohjaukseen on monia tapoja, mutta tässä työssä ohjaus on toteutettu käyt-

täen Hitachi HD44780-ohjainpiiriä [18]. Ohjainpiirin tehtävä on siis hoitaa edellä mainittu

yksittäisten pikseleiden päälle kytkentä ja tällä tavoin mahdollistaa merkkien osoittami-

nen käyttäjälle. Ohjainpiiri on siis osa LCD-moduulia, jolloin sen ohjaaminen on mahdol-

lista kytkemällä se suoraan mikrokontrolleriin. LCD-kytkentää laitteeseen yksinkertais-

taa myös se, että samaan tapaan kuin Si4703-kehitysalustan kanssa, löytyy Hitachi

HD44780-ohjainpiiriä käyttäviin LCD-näyttöihin valmis Arduino-kirjasto nimeltään Li-

quidCrystal [18]. Si4703-kehitysalustan tavoin tämä kirjasto siis sisältää valmiit funktiot,

joiden avulla tekstin saaminen LCD-näytölle ja sitä kautta käyttäjälle onnistuu äärimmäi-

sen kätevästi.

### 2.4 Audiovahvistinkytkentä

Si4703-kehitysalusta mahdollistaa FM-taajuuksien demoduloinnin audiosignaaliksi.

Tämä audiosignaali on kuitenkin varsin heikko, jolloin se tulee vahvistaa jotenkin, jotta

se on mahdollista toistaa kaiuttimesta. Tähän tehtävään avuksi tulee audiovahvistinkyt-

kentä. Tässä työssä yksinkertainen audiovahvistin on toteutettu käyttäen LM386 IC:tä.

LM386 on matalan käyttöjännitteen audiovahvistin [19, s.1], joka siis tämän työn kohdalla

vahvistaa Si4703-kehitysalustalta tulevan audiosignaalin kaiutinta varten. Kuvassa 7 on

esitettynä tässä työssä käytetty kytkentä.

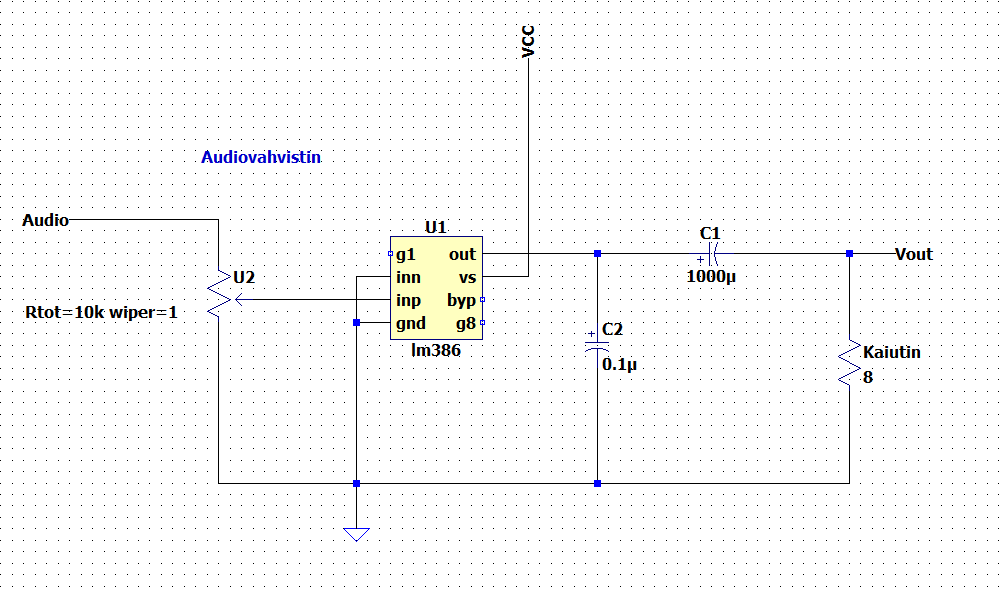
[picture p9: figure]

Kuva 7. LM386-audiovahvistinkytkentä LT Spice-ohjelmassa esitettynä.

Kuvassa 7 olevassa kytkennässä on otettu vaikutteita LM386-datalehden mallikytken-

nästä. Tällä kyseisellä kytkennällä vahvistus on 26 dB, joka tässä sovelluskohteessa

riittää mainiosti. [19 s. 10] Kytkentää on kuitenkin muokattu hieman mahdollistamaan

paras mahdollinen toiminta. Keskeisin tällainen muutos on nähtävissä kuvan 7 konden-

saattorissa C1. Datalehden mallissa tämän kondensaattorin arvoksi on määritetty 250

µF. Tämä arvo on kuitenkin aivan liian matala musiikin kuunteluun, koska tällaisessa

tilanteessa vahvistimen ulostulo toimii eräänlaisena ylipäästösuotimena. Toisin sanoen

toistettavat musiikin alimmat taajuudet määräytyvät tämän kondensaattorin mukaan ja

mikäli tämän kondensaattorin arvo on liian matala, suodattuvat matalat bassotaajuudet

pois musiikista.

Audiovahvistimen -3 dB-rajataajuus voidaan määrittää seuraavanlaisilla laskukaavoilla

1 f−3dB = 2πRC | (1)
1 C = 2πRf−3dB | (2)

, jossa R on vahvistimen kuorma eli tässä tilanteessa kaiuttimen vastus ohmeina, f−3dB

on audiovahvistimen -3 dB-rajataajuus ja C on ulostulossa olevan kondensaattorin C1

kapasitanssi [20, luku 5.8]. Koska kaiuttimen halutaan toistavan audiosignaalin taajuuk-

sia mahdollisimman laajalta alueelta, tulee kondensaattorille C1 valita mahdollisimman

suuri kapasitanssin arvo tiettyjen viitearvojen sisältä. Tässä tilanteessa nämä viitearvot

määrittää ihmisen kuuloalue.

Musiikin bassotaajuudet, joita audiovahvistimen tulee toistaa, sijoittuvat välille 20Hz-

300Hz [21, luku 1.12]. Kondensaattoria C1 määrittäessä kannattaa sen arvo valita siten,

että vahvistinpiiri itsessään ei rajoita näiden taajuuksien toistamista. Näin ollen voidaan

kaavan 2 mukaisesti laskettuna todeta, että ulostulokondensaattorin arvo tulisi olla 20

Hz:n taajuudella noin 1000 µF. Tällä ulostulokondensaattorin C1 arvolla myös alimmat

bassotaajuudet kuuluvat nyt audiovahvistimen ulostulon taajuusalueeseen. Huomioita-

vaa tässä on kuitenkin se, että datalehden mukaisella 250 µF arvolla kaiuttimen –3 dB-

rajataajuus olisi sen sijaan n. 80Hz kohdalla. Tällä kondensaattorin arvolla audiovahvis-

tin siis suodattaisi pois suuren osan musiikin alimmista bassotaajuuksista.

Muuta huomioitavaa tässä audiovahvistinkytkennässä on se, että lopullista äänenvoi-

makkuuden säätöä ei toteuteta kuvassa 7 näkyvällä säätövastuksella, vaan digitaalisesti

luodun ohjelmiston avulla. Kuvan 7 säätövastus on kuitenkin sijoitettu lopulliseen ko-

koonpanoon hienosäätöelementiksi eli sen avulla voidaan varmistaa, että ulostuleva

ääni ei säröydy, vaikka audiovahvistimeen saapuva ääni olisi suurin mahdollinen. Sää-

tövastuksen avulla voidaan siis luoda ikään kuin rajoitin, joka varmistaa suurimman mah-

dollisen äänenvoimakkuuden valinnan.

### 2.5 Regulaattorikytkentä

Käyttöjännitteen määrittely on erittäin tärkeä osa elektroniikkalaitteen suunnittelua.

Tässä tilanteessa käyttöjännitteen määrittely on melko yksinkertaista, koska Si4703-ke-

hitysalusta käyttää käyttöjännitteenään ja logiikkatasonaan 3,3 V:n jännitettä. Dataleh-

den mukaisesti Si4703-kehitysalustaa on mahdollista käyttää 5 V:n käyttöjännitteelle,

mutta moduulin logiikkatasona on tässäkin tapauksessa 3,3 V:n jännite. Mikäli kehitys-

alusta kytkettäisiin suoraan 5 V:n jännitteeseen, voisi tämä jännite pahimmassa tapauk-

sessa tuhota laitteen. Jos kehitysalustaa jostain syystä haluttaisiin käyttää 5 V:n jännit-

teellä tulisi logiikkatasojen väliin kytkeä niin sanottu logiikkatasomuunnin. [8] Tällaisen

logiikkatasomuuntimen tarve voidaan kuitenkin poistaa suunnittelemalla laite käyttä-

mään koko ajan 3,3 V:n jännitettä, koska tällaisessa tilanteessa laitteen muut osat eivät

vaadi edellä mainittua 5 V:n jännitettä. Tässä työssä laite saa jännitteensä neljältä sar-

jaan kytketyltä AA-paristolta. Tällaisen paristokytkennän napojen välinen jännite on 6 V.

Tämä jännite on kuitenkin liian suuri syötettäväksi suoraan järjestelmään, minkä vuoksi

se tulee reguloida.

Jänniteregulaation keskeisin tavoite on pitää laitteen käyttöjännite vakiona kuormavirran,

ympäristötekijöiden tai tulojännitteen muuttuessa [2, s.239-240]. Tämän työn osalta

kuormavirta pysyy suhteellisen vakiona laitteen operoidessa, mutta laitteen tulojännite ja

ympäristötekijät ovat muuttuvia parametrejä, jotka tulee huomioida suunnittelussa. Var-

sinkin laitteen tulojännite muuttuu hyvinkin paljon paristojen tyhjentyessä. Vastaavasti

ympäristötekijät muuttuvat riippuen siitä, missä lämpötilassa laitetta käytetään.

Pääsääntöisesti regulointimenetelmät jaetaan kahteen eri luokkaan riippuen siitä, onko

reguloitava kuorma rinnan- vai sarjaankytketty regulaation suorittavan säätöelementin

kanssa [23, s.300]. Nykyaikana kuitenkin yleisempi menetelmä varsinkin regulaattori

IC:den kohdalla on sarjaregulointi, jossa säätöelementti on toteutettu transistoripiirin

avulla [2, s.240]. Tässä työssä käytetty regulaattorikytkentä on lineaarinen, joka tarkoit-

taa sitä, että säätöelementti toimii lineaarisella alueella [23, s.301]. Toisin sanoen regu-

laattorin toimiessa sen käyttöalueella, muuttaa säätöelementti toimintaansa lineaarisesti

siten, että lähtöjännite pysyy vakiona kuormavirran tai tulojännitteen muuttuessa. Line-

aaristen regulaattorien negatiivisena puolena on kuitenkin tulon ja lähdön välisestä po-

tentiaalierosta syntyvät tehohäviöt ja siten alhaisempi hyötysuhde [2, s.244].

Lineaarisen regulaattorin sijasta olisi mahdollista käyttää niin kutsuttua hakkuriteholäh-

dettä (switching regulator), jonka hyötysuhde on lineaarisia regulaattoreita parempi [23,

s.323]. Hakkuriteholähteiden haittana taas on se, että ne ovat useasti rakenteeltaan monimutkaisempia [23, s.323]. Tämän edellä mainitun seikan vuoksi on tässä työssä pää-

dytty käyttämään lineaarista teholähdettä niiden yksinkertaisuuden ja halvan hinnan

vuoksi. Lisäksi potentiaaliero regulaattorin tulon ja lähdön välillä sekä kuormavirta (n. 50

mA) ovat tässä työssä niin pieniä, että merkittävää tehohäviötä ei synny, vaikka ky-

seessä onkin lineaarinen regulaattorikytkentä.

Tähän työhön valikoitunut regulaattori on lineaarinen Texas Instrumentsin valmistama

LM1117 IC, jolla luotu kytkentä on esitetty alla olevassa kuvassa 8. Tätä kyseistä regu-

laattoria valmistetaan useammalle eri jännitearvolle, mutta koska tässä tilanteessa jän-

nitteen halutaan pysyvän koko ajan 3,3 V:n arvossa, voidaan valita malli, missä jännite

on “lukittu” tähän arvoon.

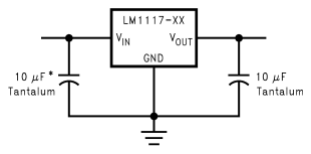
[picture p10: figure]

Kuva 8. Regulaattorikytkentä [22, s.16].

Regulaatiopiiriä suunnitellessa on kuitenkin tärkeää muistaa, että jännitteen alentami-

sesta syntyy aina tehohäviötä, joka muuttuu regulaattori IC:n kohdalla lämmöksi. Tällöin

tulojännitteen valinnassa kannattaa pyrkiä siihen, että potentiaaliero tulo- ja lähtöjännit-

teen välillä on mahdollisimman pieni. Tässä työssä kuormavirta on hyvin pieni, minkä

vuoksi LM1117 IC:n jäähdytyksestä ei tarvitse välittää. Kuitenkin jos potentiaaliero tulo-

ja lähtöjännitteen välillä olisi suurempi, voisi pienikin kuormavirta aiheuttaa IC:n merkit-

tävää lämpenemistä [2, s.242]. Joka tapauksessa kannattaa hukkatehon määrä aina mi-

nimoida. Tulon ja lähdön välinen potentiaaliero ei myöskään saa olla liian pieni, koska

tällöin regulaattori ei kykene luotettavaan toimintaan.

Regulaattorien tapauksessa tästä minimipotentiaalierosta käytetään nimitystä pudotus-

jännite (dropout voltage). LM1117:n datalehdellä on mainittu, että 100 mA kuormavirralla

tulo- ja lähtöjännitteen ero tulee olla on ainakin 1,2 V [22, s.6]. Tästä syystä työhön on

valittu jännitelähteeksi 6 V:n paristokytkentä, sillä 6 V:n jännite on tarpeeksi suuri mah-

dollistamaan regulaattorin varma toiminta, mutta samalla 6 V:n ja 3,3 V:n välinen poten-

tiaaliero on niin pieni, että merkittävää tehohäviötä ei synny.

Tämän työn simulaatio-osiota varten on tärkeää määrittää laskukaava regulaattorikyt-

kennän tehohäviölle. Ohjeet tehohäviön laskemiseen on esitetty yksityiskohtaisesti

LM1117-datalehdellä. Tältä datalehdeltä löytyvät alla esitetyt laskukaavat 3 ja 4, jotka

mahdollistavat tehohäviön laskemisen. [22, s.18]

Iin = IL + IG | (3)
PD = (Vin − Vout)IL + VinIG | (4)

Kaavassa 3 Iin on tulovirta, joka samalla Kirchoffin virtalain mukaisesti on kuormavirran

IL

ja maajohtimen virran IG summa. Kaavassa 4 PD on regulaattorin lämmöksi haihtuva

tehohäviö, Vin on tulojännite ja Vout on lähtöjännite. Lisää regulaattorikytkennän simu-

loidusta tehohäviöistä on kerrottu luvussa 3.2.

## 3. SUUNNITTELUN VAIHEET

Elektroniikkalaitteen suunnittelu kannattaa aloittaa sen ominaisuuksien määrittelystä.

Suunnittelun alkuvaiheessa kannattaa siis tarkkaan miettiä, mitä laitteen tulee pystyä

suorittamaan. Tämän työn osalta tämä vaihe on melko suoraviivainen, koska FM-radio

laitteena on monelle jo entuudestaan hyvin tuttu. Näin ollen laitteen määrittely on suu-

rimmalta osin tehty jo valmiiksi.

### 3.1 Laitteen määrittely

FM-radion keskeisin tehtävä on demoduloida ja toistaa FM-kantoaallolla välitetty viesti

eli FM-radioaseman lähettämä ohjelma. Kun vastaanotettu lähetys on saatu demoduloi-

tua, tulee tämä sisältö vahvistaa ja toistaa kuuntelijalle. FM-signaalin demoduloinnin ja

vahvistamisen suorittaa tässä työssä Si4703-kehitysalusta. Demoduloinnin jälkeen au-

diosignaali tulee saada siirrettyä kaiuttimelle käyttäjän kuunneltavaksi. Tähän tehtävään

tarvitaan siis jonkinlainen audiovahvistin sekä kaiutin, joka toistaa vastaanotetun sano-

man. Kaikissa tilanteissa audiosignaalia ei haluta toistaa samalla voimakkuudella, minkä

vuoksi äänenvoimakkuuden säätö tulee myös ottaa osaksi laitteen suunnittelua.

Äänenvoimakkuuden säätämisen lisäksi tulee soitettavaa FM-taajuutta pystyä muutta-

maan. Taajuuden vaihto tapahtuu kolmen erillisen kytkimen avulla, joiden avulla FM-

taajuusalueelta voidaan etsiä kanavia liikkuen ylös- ja alaspäin yhden desimaalin tark-

kuudella. FM-taajuuden säätö yhden desimaalin tarkkuudella on tärkeä lisä laitteeseen,

koska ylös- ja alaspäin etsittäessä Si4703-kehitysalusta etsii kanavia niiden signaalite-

hon perusteella. Tällöin on mahdollista, että kehitysalusta ohittaa joitakin kanavapaik-

koja, jos niiden signaaliteho on liian heikko. Lisäämällä laitteeseen mahdollisuuden liik-

kua FM-taajuusalueella yhden desimaalin tarkkuudella, saadaan näin katettua koko FM-

taajuusalue.

FM-taajuuden säätämisen lisäksi sisältää laite vielä neljännen kytkimen, jonka tarkoitus

on resetoida laite. Resetointi on mikrokontrollerijärjestelmissä tärkeä ominaisuus, koska

se mahdollistaa vikatilanteiden korjauksen laitteen uudelleenkäynnistyksellä. Tässä

työssä radio alkaa toistamaan ohjelmistossa määritettyä kanavaa heti käynnistyksen jäl-

keen. Tällöin jos yksittäinen kanava on asetettu ohjelmistossa käynnistymään aina lait-

teen toiminnan alkaessa, voidaan RESET-kytkimellä siirtyä kuuntelemaan tätä kanavaa.

Viimeisimpänä tarvitaan laitteeseen jonkinlainen näyttö, jotta käyttäjä pystyy seuraa-

maan laitteen toiminnan vaiheita eli toistettavaa FM-taajuutta ja äänenvoimakkuuden ta-

soa. Nämä tiedot ovat käyttäjälle äärimmäisen tärkeitä, koska ne ovat tämän työn osalta

ainoita parametreja, joita käyttäjä voi muuttaa laitteen toiminnan aikana. Kuvassa 9 on

esitetty lohkokaavio, johon on sisällytetty laitteen kaikki funktionaaliset lohkot.

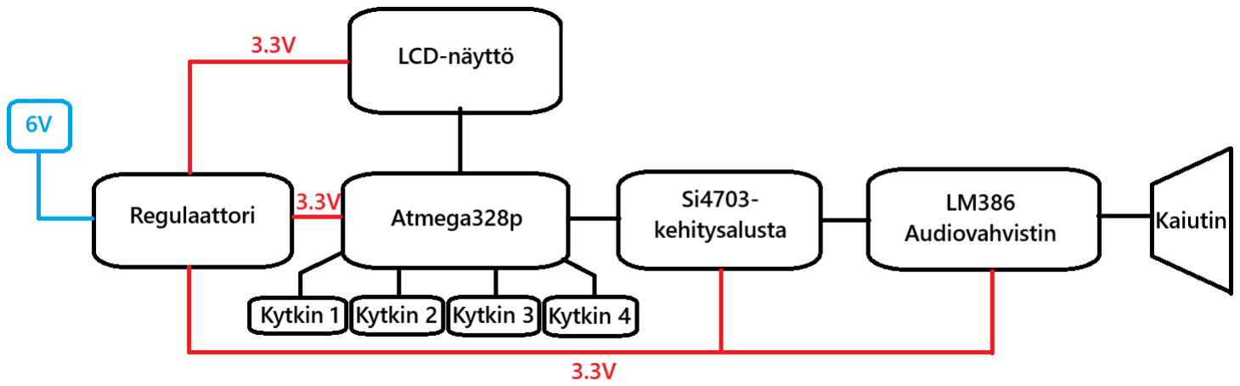
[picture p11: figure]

Kuva 9. FM-vastaanottimen lohkokaavio.

### 3.2 Osien ja lohkojen simulointi

Tämä projekti on ollut erittäin käytännönläheinen eli monia asioita on suunniteltu suoraan

koekytkentälevyllä kokeilemalla. Tämän työn osalta tällainen testaus on mahdollista,

koska käytössä olevien lohkojen osalta on ollut saatavilla runsaasti dokumentaatiota ja

ohjeita, joidenka pohjalta laitetta on ollut mahdollista rakentaa. Tämän tapaisessa tes-

tauksessa on kuitenkin riskinsä, sillä jos kytkentöihin ja ohjeistuksiin ei kiinnitä tarpeeksi

huomiota, on mahdollista että laite tai sen osia tuhoutuu.

Suurin ongelmien aiheuttaja tässä työssä on käyttöjännitteen suuruus. Ongelma muo-

dostuu siitä, että perinteinen Arduino UNO käyttää 5 V:n käyttöjännitettä ja logiikkata-

soja, kun taas tämän laitteen muut osat käyttävät 3,3 V:n käyttöjännitettä. Tätä ongelmaa

ratkaisemaan kehitettiin teoriaosuudessa kuvassa 8 esitelty regulaattorikytkentä. Ennen

laitteen lopullista rakentamista tulee kuitenkin simuloida, toimiiko tämä regulaattorikyt-

kentä odotetulla tavalla. Tällaisia simuloitavia aiheita on esimerkiksi jo teoriaosuudessa

mainittu hukkatehon määrä sekä itse regulaation onnistuminen.

Tässä työssä kaikki simulaatiot on toteutettu käyttäen LT Spice-simulaatio-ohjelmaa. Re-

gulaattoripiiriä simuloitaessa on käytetty LT Spice-ohjelman valmista komponenttia

LT1117-3.3, joka vastaa erittäin paljon työssä käytettävää LM1117-3.3 komponenttia

[24]. Lisäksi kytkennän kuormaksi on asetettu ideaalinen virtalähde, joka simuloi kytkennän koekytkentälevyltä mitattua 50 mA kuormavirtaa. Ensimmäisessä simulaatiossa tes-

tattiin komponentin regulointiominaisuuksia pyyhkäisemällä tulojännitteen arvoa välillä

0-20 V, milloin saatiin lähtöjännitteelle alla olevan kuvan 10 mukaisia tuloksia.

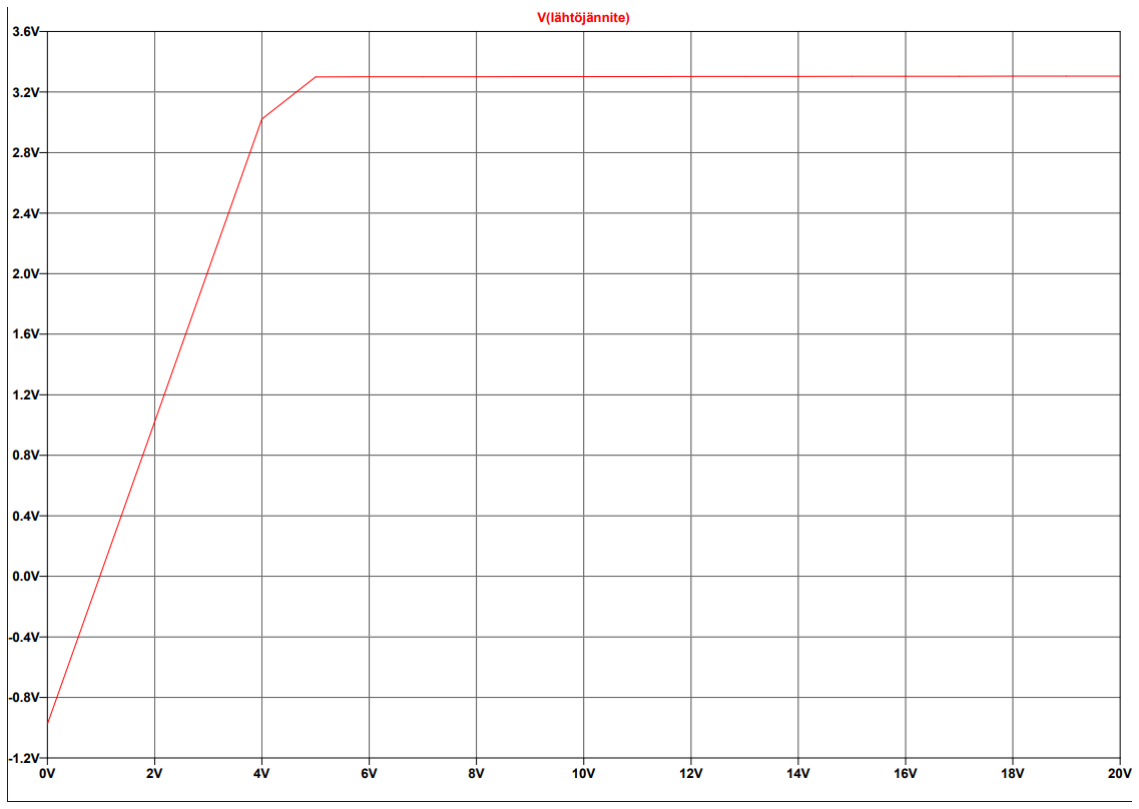
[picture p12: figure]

Kuva 10. Regulaattorikytkennän lähtöjännite tulojännitteen funktiona.

Kuvassa 10 esitettyjen tulosten perusteella voidaan päätellä, että regulaattoripiiri todella

reguloi paristoilta saadun 6 V:n jännitteen laitteelle sopivaan 3,3 V:n jännitteeseen.

Muuta huomioitavaa kuvassa 10 esitetyssä simulaatiossa on se, että siitä on nähtävillä

myös luvussa 2.5 mainitun pudotusjännitteen vaikutus. Kuten kuvasta 10 voidaan huo-

mioida, on lähtöjännitteen arvo alle 3,3 V, kunnes tulojännite saavuttaa 5 V:n jännitteen.

Toisin sanoen regulaattori ei kykene saavuttamaan 3,3 V jännitearvoa, jos paristokyt-

kennän jännite on alle lähtöjännitteen ja pudotusjännitteen summan verran. Laskennal-

lisesti LM1117:n pienin tulojännite, jolla regulaattorin tulisi vielä toimia on 4,5 V, jos las-

kuissa käytetään pudotusjännitteen arvoa 1,2 V [22, s.6]. Simulaation mukaan pienin

arvo, jolla regulaattori toimii on 5 V, josta voidaan tehdä päätelmä, että laskennallinen ja

simuloitu arvo vastaavat toisiaan melko hyvin. Tärkeimpänä huomiona voidaan kuitenkin

todeta, että suunniteltu 6 V:n paristokytkentä on riittävä laitteen toiminnan takaamiseksi.

Muita ominaisuuksia, mitä regulaattorikytkennästä kannattaa simuloida on sen tehohä-

viö. Kappaleen 2.5 mukaisesti, lineaarisen regulaattorin tehohäviö muuttuu komponentin lämmöksi. Simulaation avulla voidaan siis varmistua siitä, että LM1117-komponentti ei

lämpene liikaa laitteen lopullisessa versiossa. Monet regulaattori-IC:t, kuten myös

LM1117 sisältää sisäänrakennetun sulkuominaisuuden, joka käytännössä tarkoittaa sitä,

että komponentti sammuttaa itsensä mikäli sen lämpötila kasvaa liian suureksi [22, s.18].

Tästä syystä on tärkeää tarkistaa, että komponentti ei lämpene liikaa.

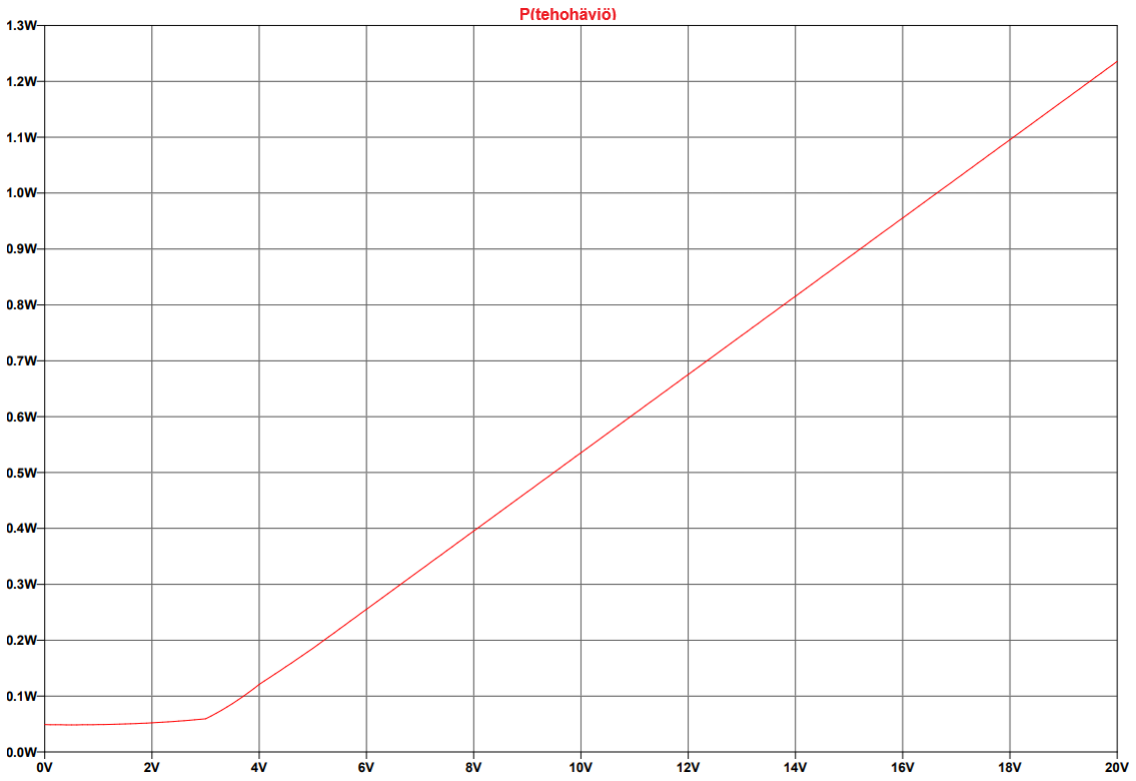
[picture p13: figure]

Kuva 11. Regulaattorikytkennän tehohäviö tulojännitteen funktiona.

Yllä olevasta kuvasta 11 Voidaan nähdä, että 6 V:n tulojännitteellä regulaattorikytkennän

tehohäviö on n. 0.25 W. Tästä voidaan tehdä päätelmä, että regulaattori ei lämpene tä-

män laitteen toimintatarkoituksissa suuresti, joten sen jäähdyttämisestä ei tarvitse huo-

lehtia. Merkittävä huomio kuvasta 11 on kuitenkin se, että jopa 50 mA kuormavirralla

regulaattorin tehohäviö pystyy nousemaan jo yli yhden watin. Tämä on hyvä esimerkki

kappaleessa 2.5 tehdystä huomiosta, jonka mukaan lineaaristen regulaattorien hyöty-

suhteet ovat alhaiset, jos potentiaaliero tulon ja lähdön välillä kasvaa suureksi.

Viimeisimpänä simuloinnin kohteena on laitteessa käytettävä audiovahvistinkytkentä.

Audiovahvistinkytkennän simulointi on mielekästä, sillä sen avulla on mahdollista mää-

rittää vahvistimen suuntaa antava taajuusvaste. Tässä työssä käytetty audiovahvistin on

LM386 IC, jolle valmistaja Texas Instruments ei kuitenkaan suoraan ole luonut LT Spice-

simulointimallia. Internetin foorumeilla on kuitenkin saatavilla muiden käyttäjien luomia

LT Spice-malleja kyseiselle komponentille [25], jonka avulla kytkennän toimintaa voidaan

testata. Saatuihin tuloksiin tulee kuitenkin suhtautua varoen, koska kyseessä ei ole Te-

xas Instrumentsin virallinen simulointimalli. Tämän mallin avulla on kuitenkin mahdollista

simuloida, vastaavatko laskennallinen ja simuloitu -3 dB-rajataajuus toisiaan. Audiovah-

vistinkytkennän simulaatiotulokset on esitetty alla olevassa kuvassa 12.

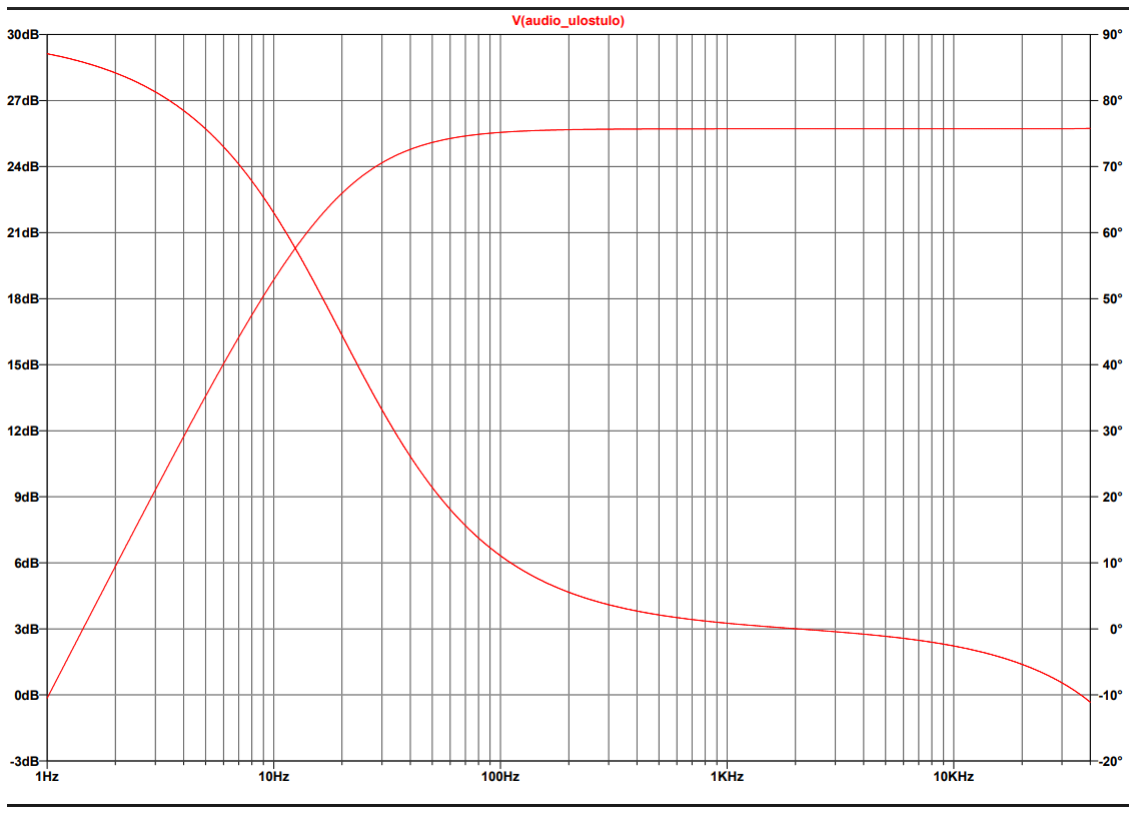
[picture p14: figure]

Kuva 12. Audiovahvistinkytkennän taajuusvaste.

Kuvassa 12 on 0 dB kohdalta alkava käyrä ulostulosignaalin amplitudi. Toinen käyrä

esittää vaiheen muutosta taajuuden funktiona. Amplitudi on yllä olevassa kuvassa skaa-

lattu 3 dB välein, jolloin -3 dB -pisteen etsiminen helpottuu. Kuvasta 12 voidaan siis

nähdä, että audiovahvistimen -3 dB -piste on noin 20 Hz kohdalla. Tämä tulos vastaa

kappaleessa 2.4 laskettua arvoa ja näin ollen voidaan todeta, että ulostulokondensaat-

torin uudelleenmitoituksella todella on vaikutusta audiovahvistimen taajuusvasteeseen.

Kuten edellä mainittiin, on tämä simulaatio kuitenkin vain suuntaa antava sen vuoksi,

että simulaatiomallin oikeellisuudesta ei voida tässä tilanteessa olla aivan varmoja.

LM386-datalehden mukaan tässä työssä käytetyn audiovahvistinkytkennän vahvistus tu-

lisi olla n. 26 dB [19, s.10], mistä voidaan päätellä, että simulaation tulokset vaikuttavat

loogisilta.

### 3.3 Ohjelmiston suunnittelu

Työtä varten luotu ohjelmisto on rakenteeltaan hyvin yksinkertainen ja kompakti. Syynä

tälle on se, että ohjelmiston rakentamisessa on voitu tehokkaasti hyödyntää Si4703 IC:lle

ja LCD-näytölle luotuja valmiita ohjelmistokirjastoja. Tästä seuraa se, että funktiot, joita

laitteen operointiin tarvitaan, on jo määritetty valmiiksi ohjelmistokirjastoihin. LCD-näytön

ohjaukseen tarkoitettu LiquidCrystal-kirjasto on tässä työssä jätetty koskemattomaksi,

mutta Si4703-kirjastoon on sen sijaan tehty hieman muutoksia, jotka parantavat laitteen

kuuluvuutta.

Si4703-kirjastoon tehty muutos liittyy laitteen alustukseen, jossa määritellään se, miten

Si4703 IC prosessoi vastaanotettua FM-signaalia. 1960-luvulta asti radiosignaalilähetyk-

set on toteutettu käyttäen niin kutsuttua stereo multipleksointia (MPX), jossa mono ja

stereo audiosignaali on jaettu stereo pilottisignaalin molemmille puolille [11, s.16]. MPX-

signaali on kuvattuna alla olevassa kuvassa 13.

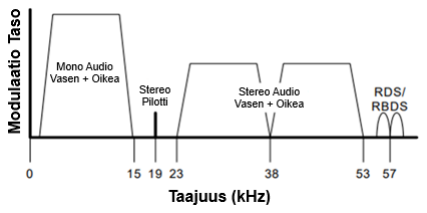
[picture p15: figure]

Kuva 13. MPX-signaalin rakenne [mukaillen lähteestä 11, s.16].

Koska MPX-signaali sisältää sekä stereo- että monosignaalin, pystyy Si4703 IC teke-

mään signaalin vahvuuden perusteella päätöksen siitä, kumpaa signaalia se päättää

käyttää [11, s.16-17]. Tämän työn osalta on kuitenkin käytännöllisempää pakottaa IC

toistamaan pelkästään monosignaalia, koska itse laitteessa kaiuttimia on vain yksi. Toi-

sin sanoen stereoprosessointi vie IC:ltä turhia resursseja, vaikka itse stereoaudiota ei

voida toistaa. IC:n pakottaminen toistamaan monosignaalia on hyvin yksinkertaista,

koska se vaatii ainoastaan yhden laiterekisterin muokkaamista. Tämä rekisteri on data-

lehdellä mainittu POWERCFG, josta muuttamalla 13. bitin arvon ykköseksi, voidaan IC

pakottaa toimimaan monona [11, s.24].

Kun Si4703 IC:n alustus on saatu valmiiksi, voidaan aloittaa itse ohjelmakoodin kirjoitus.

Ohjelmakoodin kirjoitus on melko suoraviivaista, koska mikrokontrolleri käytännössä seuraa vain neljän kytkimen tilaa ja tekee tarvittavat toimenpiteet niiden mukaan. Kytkin-

ten lisäksi ohjelma tekee ADC-muunnoksen potentiometrin arvolle, jolla muutetaan ää-

nenvoimakkuuden tasoa. Alla olevassa ohjelmassa 1 on esitetty pääfunktio kokonaisuu-

dessaan. Lopullinen ohjelmakoodi on esitetty liitteessä D.

void loop()
{
//Lukee potentiometrin arvon ja asettaa äänenvoimakkuuden lue_volume();

//Odottaa, että SEEK UP-nappia painetaan
if (digitalRead(8)){
kanava = radio.seekUp();
}

//Odottaa, että SEEK DOWN-nappia painetaan if (digitalRead(9)){
kanava = radio.seekDown();
}

//Odottaa, että FINE TUNE-nappia painetaan if (digitalRead(10)){
kanava = kanava+1;
radio.setChannel(kanava);
}

//Rajaa taajuudet välille 87,5-108 MHz if (kanava == 0){
kanava = 875;
}

//Päivittää LCD-näytön arvon
naytto();

//200 ms viive toiminnan varmistamiseksi delay(200);
}

Ohjelma 1. Luodun ohjelmiston pääfunktio.

### 3.4 Prototyypin rakentaminen koekytkentälevyillä

Ennen piirilevyn suunnittelua ja lopullisen laitteen kasaamista tulee laitteen ja sen ohjel-

miston toimivuus testata käytännössä. Tämän tyylinen testaus saadaan parhaiten toteu-

tettua käyttäen koekytkentälevyjä ja siihen sopivia johtimia. Regulaattoripiiriä lukuun ot-

tamatta laite sisältää jo kaikki osat ja lohkot, jotka sisältyvät myös lopulliseen laitteeseen.

Prototyyppien valmistus koekytkentälevyillä käy usein vaikeaksi, jos suunniteltava laite

sisältää paljon lohkoja ja toiminnallisuuksia. Tämän työn osalta tätä sekavuutta on pyritty

vähentämään lohkojen järjestelmällisellä sijoittelulla. Kuvan 15 mukaisesti pienelle koe-

kytkentälevylle on sijoitettu audiovahvistinkytkentä, sillä se toimii itsenäisesti omana loh-

konaan. Vastaavalla tavalla Si4703-kehitysalusta ja LCD-näyttö on sijoitettu omille koe-

kytkentälevyilleen. Arduino on erotettu omaksi lohkokseen sijoittamalla se hieman sivuun

muusta laitteesta.

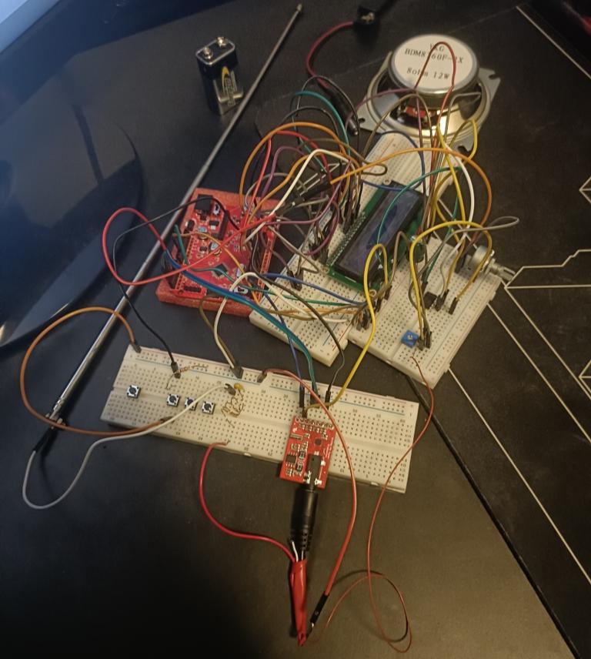
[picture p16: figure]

Kuva 15. FM-vastaanottimen prototyyppi koekytkentälevyillä.

### 3.5 Arduinon käyttö ISP-ohjelmointityökaluna

Kun ohjelmisto on todettu toimivaksi koekytkentälevyllä, tulee se ladata piirilevylle juo-

tettavaan mikrokontrolleriin. Ohjelmiston lataamiseen mikrokontrollerille on monia ta-

poja, mutta koska eräs tämän työn tavoitteista on käyttää Arduinoa mahdollisimman mo-

nessa työvaiheessa, on lopullinen ohjelma päätetty ladata mikrokontrolleriin käyttäen Ar-

duinoa itsessään ohjelmointityökaluna. Kuva ohjelmointiprosessista on esitetty alla ole-

vassa kuvassa 14.

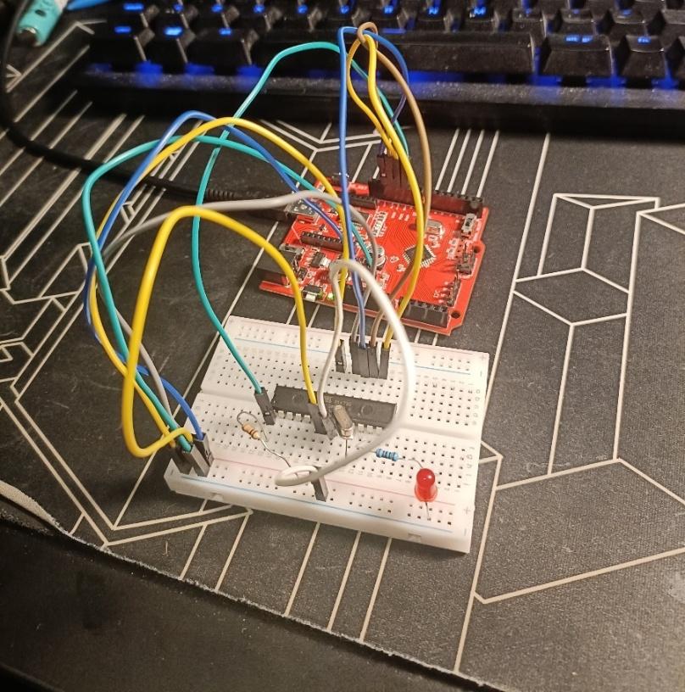
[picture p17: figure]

Kuva 14. Arduinon käyttö ISP-ohjelmointityökaluna.

Jotta Atmega328p saadaan ohjelmoitua Arduino-pohjaisella koodilla, tulee siihen ensin

ohjelmoida Arduino-bootloader [26]. Käytännössä bootloader siis alustaa asetukset,

joilla mikrokontrolleri toimii. Tällaisia asetuksia ovat esimerkiksi käytetty kellotaajuus

sekä käyttöjännite. Kun Arduinoa käytetään ISP-ohjelmointityökaluna (In-System Prog-

ramming), voidaan näitä asetuksia säätää käyttötarkoituksen mukaan. Tässä työssä

asetetaan käyttöjännitteen arvoksi 3,3 V ja kellotaajuudeksi 8 MHz.

Muita muutettavia asetuksia on BOD (Brown-out-detector), joka määrittää jännitteen jolla

Atmega328p alkaa resetoimaan itseään [6, s.40]. Tämän tarkoituksena on estää mikro-

kontrollerin virheellinen toiminta tilanteessa, jossa sen käyttöjännite laskee alle sallitun

rajan. Tämä on tärkeä ominaisuus varsinkin silloin kun mikrokontrollerin muistien sisältö

halutaan pitää eheänä. Tässä työssä ohjelma ei kuitenkaan tallenna mikrokontrollerin

pysyvään muistiin mitään, joten on tämä ominaisuus turha. Datalehden ohjeistuksen mu-

kaisesti on BOD siksi poistettu käytöstä [6, s.37].

Kun bootloader-asetukset (Fuses) on saatu valittua, voidaan itse bootloader ja luotu oh-

jelma ladata Atmega328p-mikrokontrolleriin. Ohjelmaa ladattaessa tulee varmistaa se,

että mikrokontrolleriin on kytketty sen vaatimat oheislaitteet. Nämä oheislaitteet ovat esi-

tetty teoriaosuuden kuvassa 1, joista tärkein on 8 MHz kvartsikide. Mikäli kellolähde ei

ole kytkettynä mikrokontrolleriin, antaa Arduino IDE ilmoituksen virheen merkiksi. Tämä

kellolähde on nähtävillä myös kuvan 14 tilanteessa.

### 3.6 PCB-suunnittelu

Mikrokontrollerin ohjelmoimisen ja onnistuneiden koekytkentälevykokeiden jälkeen voi-

daan luotua suunnitelmaa lähteä siirtämään PCB-levylle. Tässä tilanteessa PCB-levyn

tavoite on saada pakattua työn komponentit mahdollisimman pieneen tilaan, jotta se on

lopulta mahdollista pakata koteloon. Kytkinten ja potentiometrin sijoittelu oli tässä työssä

haastavin vaihe PCB-suunnittelussa, koska niiden sijainnilla olisi suora vaikutus kotelon

ulkonäköön ja toimivuuteen. Lopulta päädyttiin ratkaisuun, jossa kytkimet ja poten-

tiometri juotetaan samaan tasoon johdinvetojen kanssa piirilevyn pohjatasoon. Yksinker-

taisuuden vuoksi on tässä työssä piirilevy tehty yksipuoleiselle valoherkälle PCB-levylle,

jolloin kaikki johdinvedot on mahdollista tehdä yhdelle puolelle. Luotu PCB-layout on esi-

tetty alla olevassa kuvassa 16.

Kun kytkinten ja potentiometrin sijainnit oli saatu määriteltyä, voitiin muut komponentit

sijoitella piirilevylle siten, että kokonaispinta-alasta tulisi mahdollisimman pieni. Tässäkin

tilanteessa on kuitenkin pyritty järjestelmällisyyteen siinä mielessä, että samantyyppiset

komponentit, kuten vastukset ja kondensaattorit, on aseteltu omiin ryhmiinsä piirilevyllä.

IC:den kohdalla tuli tarkasti miettiä, miten ne tulisi sijoitella, koska niihin on kytkettynä

suuri määrä johdinvetoja. Myös Si4703-kehitysalustan sijoittelu tuotti vaikeuksia, koska

se sisältää itsessään jo pienen PCB-levyn. Ongelmat muodostuivat siitä, että PCB piti

saada sijoiteltua piirilevyn päälle siten, että se ei osu muihin ulospäinsuuntautuviin kom-

ponentteihin, kuten kondensaattoreihin.

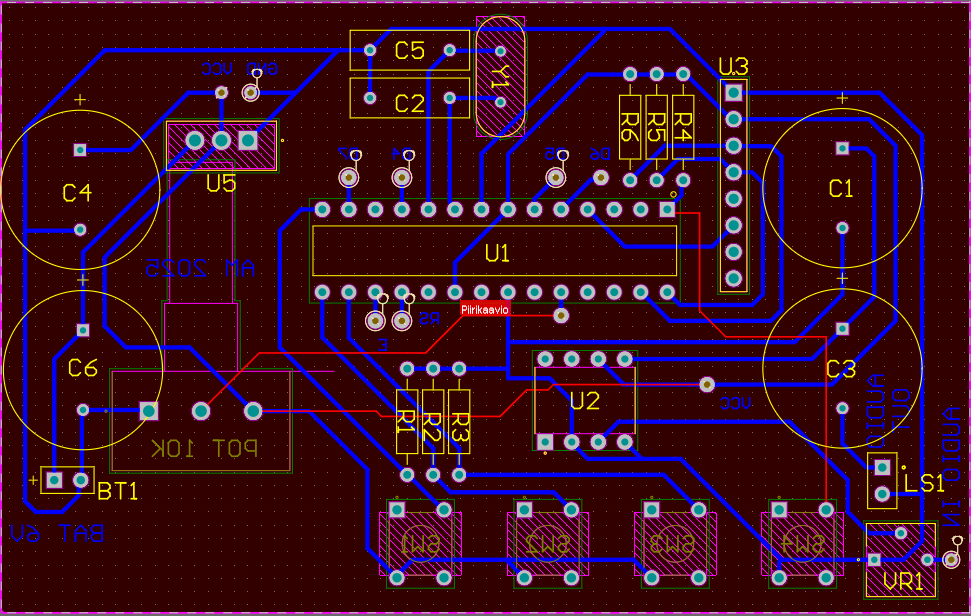
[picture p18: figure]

Kuva 16. Altium Designer-ohjelmalla luotu PCB-layout.

Keskeinen osa PCB-suunnittelua on johdinvetojen leveyden määrittäminen. Mil on piiri-

levysuunnittelussa yleisesti käytetty mittayksikkö, joka vastaa suuruudeltaan tuuman tu-

hannesosaa. Tällöin yksi mil on suuruudeltaan 0,0254 millimetriä. IPC-2221A-standardin

mukaan 10 milin johdinleveys riittäisi jopa 400 mA virrankestoon [27, s.152], mikä tämän

työn osalta olisi aivan riittävä arvo. Koska tämän työn piirilevy kuitenkin käsin valmiste-

taan etsaamalla, on tämä 10 milin arvo käytännön testauksen perusteella aivan liian

pieni. PCB:n uudemmissa versioissa nostettiin johdinvetojen leveys ja niiden väliset etäi-

syydet 20 miliin, jolloin käsin valmistuksessa tapahtuvat virheet eivät haittaa laitteen toi-

mintaa.

Koska kaikki komponentit tässä työssä ovat läpiladottavia, tulee niille porata reiät piirile-

vyyn. Perinteisesti PCB-suunnittelussa määritetään niin kutsuttu porauskartta, jossa on

esitetty porattavien reikien paikat ja halkaisijat. Tässä työssä tarvetta porauskartalle ei

kuitenkaan ole, koska potentiometriä lukuun ottamatta kaikkien komponenttien jaloille

tarkoitetuille paikoille porataan reikä. Lisäksi nämä reiät on tehty kaikki käyttäen 1 mm

poranterää, jolloin terän suuruus pysyy vakiona reikiä porattaessa.

### 3.7 Kotelointi

Kun laitteen elektroniikkaosuus on saatu valmiiksi, tulee näiden elektroniikkaosien suo-

jaksi luoda jonkinlainen kotelo. Samalla kotelosuunnittelulla voidaan parantaa laitteen

akustisia ominaisuuksia. Kotelo päädyttiin tekemään 3D-tulostamalla, koska se on tässä

tilanteessa edullisin ja tehokkain tapa luoda yksinkertainen suoja laitteen komponen-

teille.

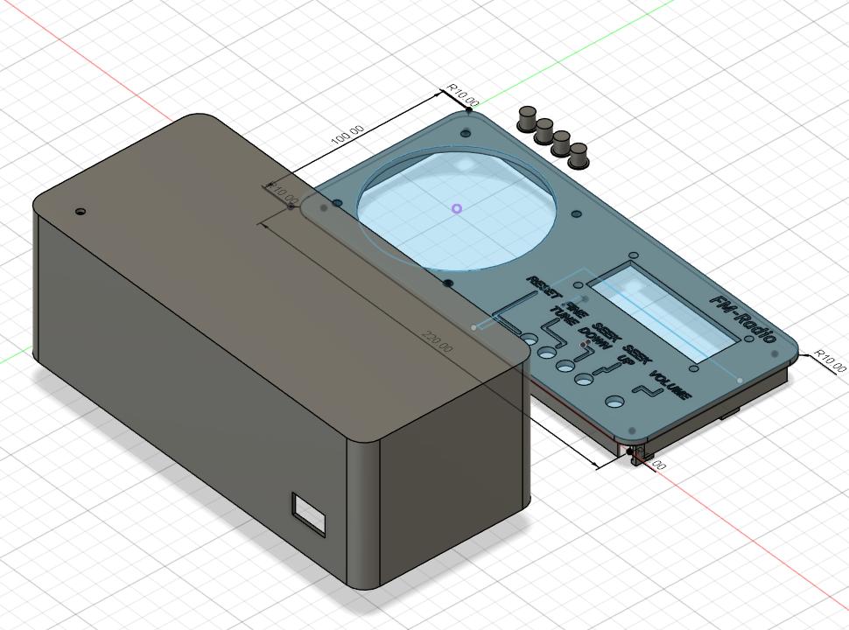
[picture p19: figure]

Kuva 17. Luotu 3D-malli Autodesk Fusion-ohjelmassa esitettynä.

Jotta kotelo on mahdollista 3D-tulostaa, tulee siitä ensin luoda 3D-malli. Tässä työssä

on 3D-mallin luomisessa käytetty Autodesk Fusion-ohjelmaa. Viimeistelty 3D-malli on

esitetty yllä olevassa kuvassa 17. 3D-mallin luomisessa on tärkeää mitata ja mallintaa

laitteen komponentit sekä niiden dimensiot mahdollisimman tarkasti. Tässä työssä on-

gelmia aiheuttavia osia ovat nimenomaan LCD-näyttö, kytkimien paikat sekä itse kaiutin.

Koska elektroniikkaosuus on kuitenkin luotu jo valmiiksi, on näiden komponenttien di-

mensiot helppo mitata työntömitan avulla. Kaikki elektroniikkaosat on kiinnitetty tässä

työssä kanteen, jolloin kotelon avaaminen esimerkiksi paristojen vaihtoa varten on help-

poa. Kaiutin ja LCD-näyttö on kiinnitetty kanteen käyttäen M3-pultteja ja muttereita. Li-

säksi kannen sisäpuolella on lovet, joihin piirilevy asettuu tiukasti paikalleen. Lisäksi pii-

rilevy kiristetään vielä kannen ulkopuolelta potentiometrin jenkoihin menevällä mutterilla.

Alla olevassa kuvassa 18 on esitelty laitteen lopullinen 3D-tulostettu kotelo ja siihen kiin-

nitetyt elektroniikkaosat.

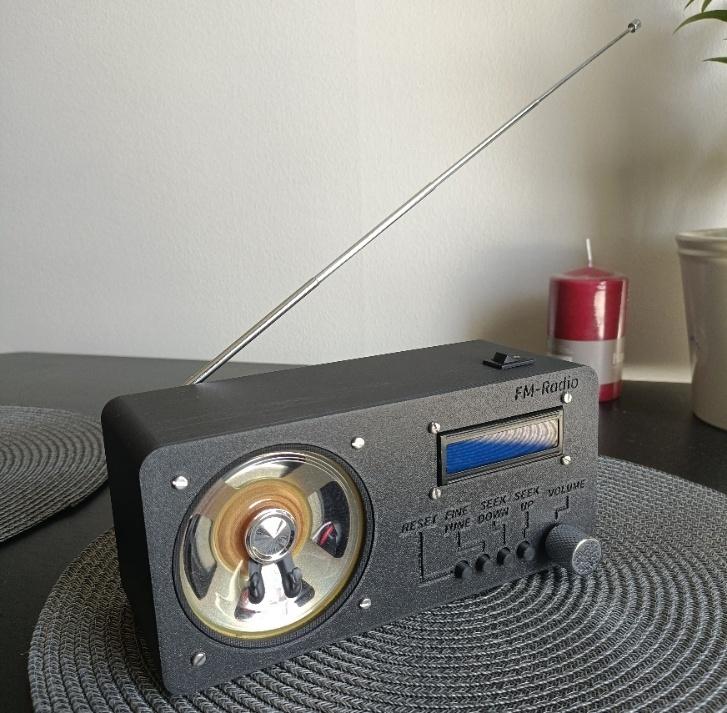
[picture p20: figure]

Kuva 18. Viimeistelty FM-vastaanotin.

## 4. YHTEENVETO

Koteloinnin myötä on FM-radio saatu valmiiksi. Laite löytää valtaosan Tampereen radio-

kanavista ja luodut ominaisuudet, kuten kanavan etsintä, hienosäätö ja äänenvoimak-

kuuden säätö, toimivat loistavasti. Olen tyytyväinen työn lopputulokseen ottaen huomi-

oon, että tämä on ensimmäinen elektroniikkalaite, jonka suunnittelen alusta loppuun itse.

Samalla opin paljon uusia asioita elektroniikkalaitteen suunnittelusta ja sen eri vaiheista.

Laite toimii tällä hetkellä hyvin, mutta varaa jatkokehityksen löytyy vielä. Esimerkiksi kap-

paleessa 2.2 mainittu RDS-dataprosessointi voisi olla hyvä lisä laitteen toimintaan.

Tässä työssä kotelon akustisiin ominaisuuksiin ei keskitytty mitenkään suuresti työn ai-

healueen rajaamiseksi. Kotelon jatkokehitys on kuitenkin vielä mahdollista, koska sen

kansi ja pohja ovat toisistaan irrallisia osia. Tällöin esimerkiksi refleksiaukon lisääminen

pohjaosaan voisi parantaa varsinkin bassotaajuuksien toistamista.

Työn johdannossa esitettiin kysymys siitä, voiko kotioloissa luoda vertailukelpoisen FM-

radion kaupallisiin radioihin verrattuna. Vastaus kysymykseen riippuu hyvin paljon siitä,

minkälaisia ominaisuuksia radioon haluaa. Mikäli käyttäjä haluaa radion, joka yksinker-

taisesti vain toistaa halutun FM-taajuuden kannattaa tällöin valita kaupallinen tuote nii-

den halvan hinnan vuoksi. Mikäli käyttäjä haluaa RDS-prosessointiin kykenevän ja mah-

dollisesti vain nappikuulokkeilla toimivan radion, kannattaa tällöin valita Si4703-kehitys-

alustalla tehty radio. Vaikka rahallisesti kotioloissa tehty FM-radio ei olisi kilpailukykyinen

kaupallisten radioiden kanssa, voi itse tehdessä laitteen ominaisuudet räätälöidä omiin

käyttötarkoituksiin sopivaksi.

Elektroniikkalaitteen suunnittelussa ja rakentamisessa tulee ottaa huomioon, että se voi

tarjota tekijälleen kokemuksia ja ideoita, joita ei välttämättä voi rahallisesti mitata. Ar-

duino-alusta kykenee tehokkaasti toimimaan lähes jokaisessa elektroniikkalaitteen suun-

nittelun vaiheessa aina suunnittelusta lopullisen kokoonpanon ohjelmointiin. Joissakin

tilanteissa saatetaan Arduino jopa jättää osaksi viimeisteltyä laitetta sen halvan hinnan

vuoksi. Arduino on työkaluna monipuolinen ja käyttäjäläheinen, minkä vuoksi sen me-

nestys ja suuri suosio elektroniikan harrastajien ja ammattilaisten keskuudessa ei ole

ihme.

## LÄHTEET:

[1] What is Arduino?, Arduino, 2018. Saatavissa (viitattu 31.3.2025): https://www.arduino.cc/en/Guide/Introduction/
[2] K. Silvonen, Elektroniikka ja sähkötekniikka, Gaudeamus, Otaniemi, 2018, 504 s.
[3] RayMing, What Are Breakout Boards / SMT Breakout PCB ?, RayPCB, 2025. Saatavissa (viitattu 31.3.2025): https://www.raypcb.com/smt-breakout-boards/
[4] Jeff, Schematic of a Breadboard Arduino, Fiz-ix, 2012. Saatavissa (viitattu 31.3.2025): https://fiz-ix.com/2012/11/schematic-of-a-breadboard-arduino/
[5] Arduino Integrated Development Environment (IDE) v1, Arduino, 2025. Saatavissa (viitattu 8.5.2025): https://docs.arduino.cc/software/ide-v1/tutorials/arduino-ide-v1-basics/
[6] Atmel-7810-Automotive-Microcontrollers-ATmega328P_Datasheet, Atmel, 2015. Saatavissa
(viitattu | 31.3.2025): | https://ww1.microchip.com/downloads/aemDocuments/docu-
ments/MCU08/ProductDocuments/DataSheets/Atmel-7810-Automotive-Microcontrollers-ATmega328P_Datasheet.pdf
[7] D. Wheat, Arduino Internals, 1st ed. 2011, Apress, Berkeley, 2011, 329 s.
[8] Si4703 FM Radio Receiver Hookup Guide, SparkFun Learn, 2025. Saatavissa (viitattu
1.4.2025): | https://learn.sparkfun.com/tutorials/si4703-fm-radio-receiver-hookup-
guide?_ga=1.110826
[9] Arduino Pro Mini, Arduino, 2025, Saatavissa (viitattu 8.5.2025): https://docs.arduino.cc/retired/boards/arduino-pro-mini/
[10] KIDE 8,000000MHz HC49/4H (matala), PARTCO, 2025. Saatavissa (viitattu 11.5.2025): https://www.partco.fi/fi/elektroniikan-komponentit/passiivit/kiteetoskillaattorit/kiteet-tht/6145-kide-8mhz-4h.html
[11] Si4702-03-C19, Silicon Labs, 2009. Saatavissa (viitattu 8.4.2025): https://cdn.sparkfun.com/assets/f/0/9/0/1/Si4702-03-C19-1.pdf
[12] D. Russell, Introduction to Embedded Systems: Using ANSI C and the Arduino Development Environment. Cham, Switzerland, 2010, 264 s.
[13] Toni Klopfenstein, Si4703_FM_Tuner_Evaluation_Board/Libraries/Arduino/src, Sparkfun, 2015, päivitetty 12.9.2018. Saatavissa (viitattu 28.4.2025): https://github.com/sparkfun/Si4703_FM_Tuner_Evaluation_Board/tree/master/Libraries/Arduino/src
[14] AN383: Si47xx Antenna, Schematic, Layout, and Design Guidelines, Skyworks Solutions Inc.,2007, päivitetty 23.1.2025. Saatavissa (viitattu 8.4.2025): https://www.skyworksinc.com/-/media/Skyworks/SL/documents/public/application-notes/AN383.pdf
[15] N. Seidle, Toni Klopfenstein, Si4703_Eval_v13.sch, 2014, päivitetty 1.7.2024. Saatavissa
(viitattu | 28.4.2025): | https://cdn.sparkfun.com/datasheets/Wireless/Gene-
ral/Si4703_Eval_v13.pdf
[16] D. J. R. Cristaldi, S. Pennisi, ja F. Pulvirenti, Liquid crystal display drivers: techniques and circuits, Dordrecht: Springer, 2009, 295 s.

[17] TN-LCD-schematic-MS-208kB.png, Wikimedia Commons, 2007. Saatavissa (viitattu 11.5.2025): https://commons.wikimedia.org/wiki/File:TN-LCD-schematic-MS-208kB.png
[18] Liquid Crystal Displays (LCD) with Arduino, Arduino, 2025. Saatavissa (viitattu 11.5.2025): https://docs.arduino.cc/learn/electronics/lcd-displays/
[19] LM386 Low Voltage Audio Power Amplifier, Texas Instruments, 2004, päivitetty 08/2023. Saatavissa (viitattu 8.4.2025): https://www.ti.com/lit/ds/symlink/lm386.pdf
[20] Lam JCM, Analog Audio Amplifier Design, 1st ed, Oxford: Taylor & Francis Group, 2024, 598 s.
[21] B. Duncan, High perfomance audio power amplifiers for music performance and reproduction, Oxford Boston: Newnes, 1996, 463 s.
[22] LM1117 800-mA, Low-Dropout Linear Regulator, Texas Instruments, 2000, päivitetty 01/2023. Saatavissa (viitattu 8.4.2025): https://www.ti.com/lit/ds/symlink/lm1117.pdf
[23] J. Fiore, Operational Amplifiers & Linear Integrated Circuits: Theory and Application, 3e p, Itsejulkaisu, 2018, 556 s.
[24] LT1117 Datasheet and Product Info, Linear Technology, 1993, päivitetty 04/2010. Saatavissa
(viitattu | 3.5.2025): | https://www.analog.com/media/en/technical-documentation/data-
sheets/1117fd.pdf
[25] Roff, Spice model LM386, Electro-Tech-Online, 2006. Saatavissa (viitattu 11.5.2025): https://www.electro-tech-online.com/threads/spice-model-lm386.23296/
[26] Arduino as ISP and Arduino Bootloaders, Arduino, 2025. Saatavissa (viitattu 8.5.2025): https://docs.arduino.cc/built-in-examples/arduino-isp/ArduinoISP/
[27] K. Mitzner, Complete PCB Design Using Orcad Capture and Layout, Elsevier Science & Technology, Chantilly, USA, 2007, 529 s.

# LIITE A: Piirikaavio

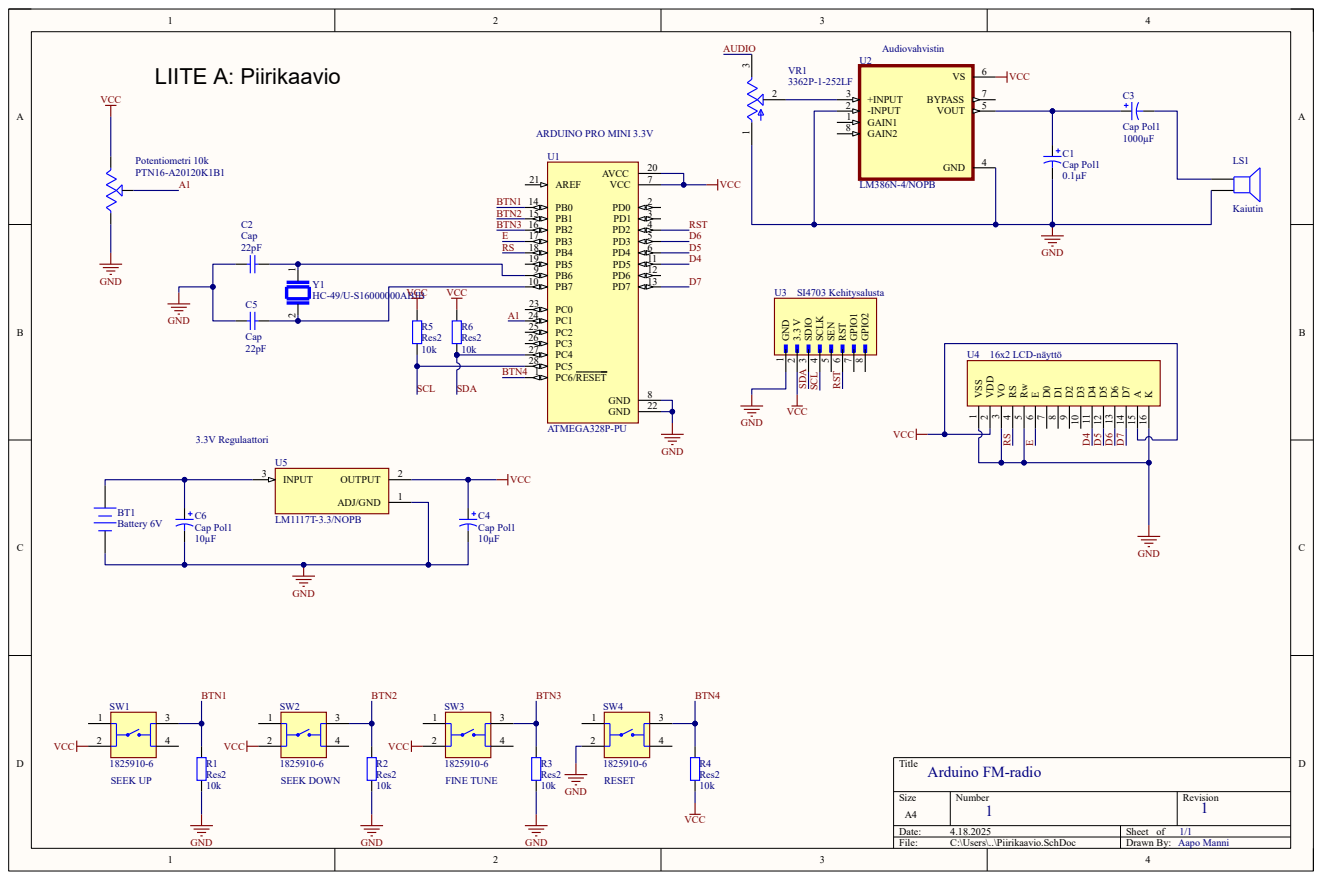
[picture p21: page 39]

# LIITE B: Valotusmaski

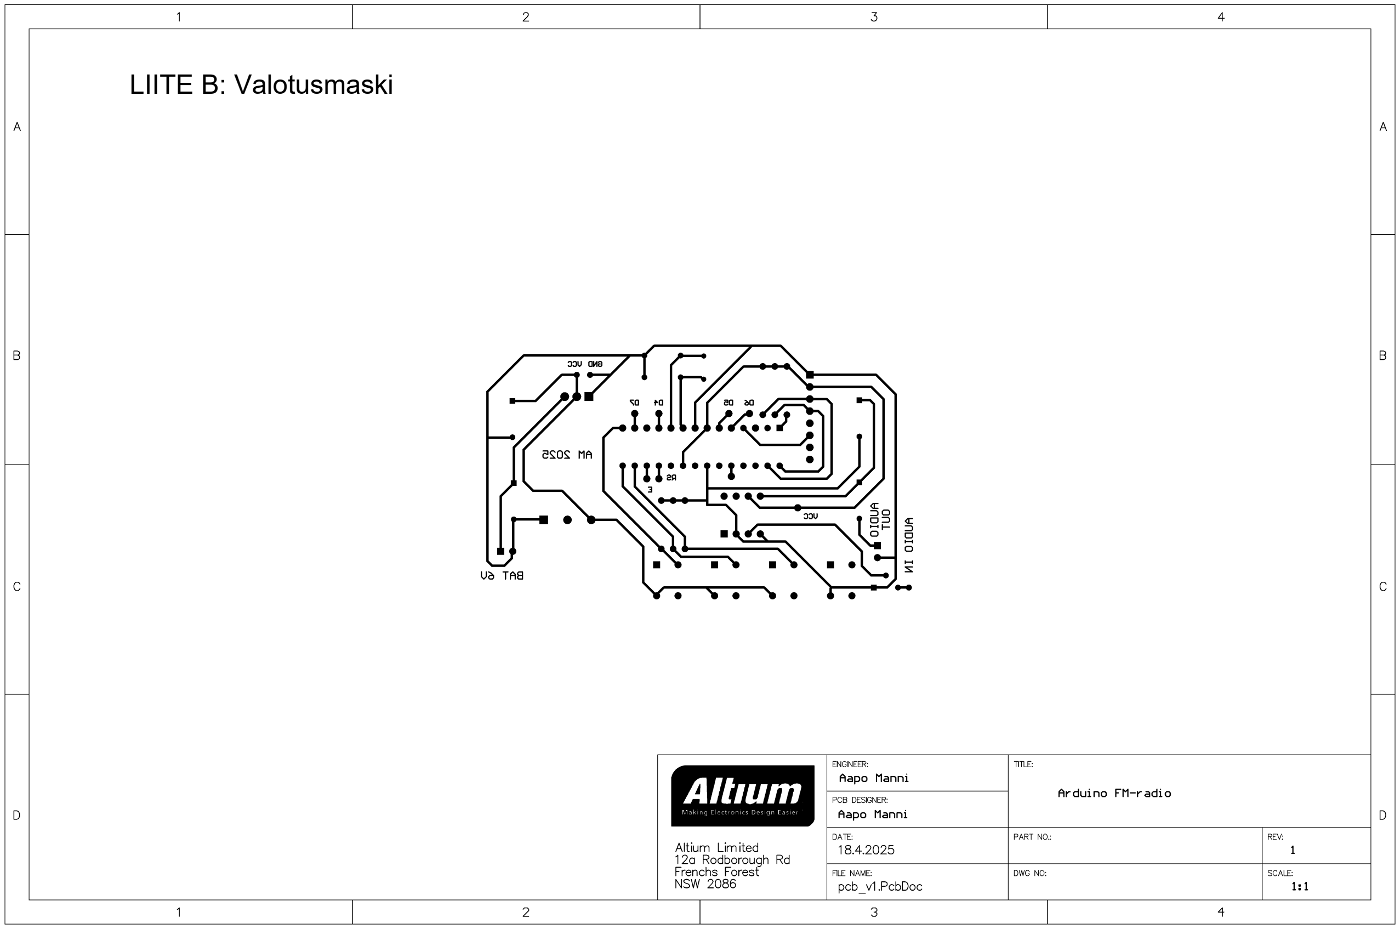
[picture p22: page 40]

# LIITE C: Osasijoittelukuvat

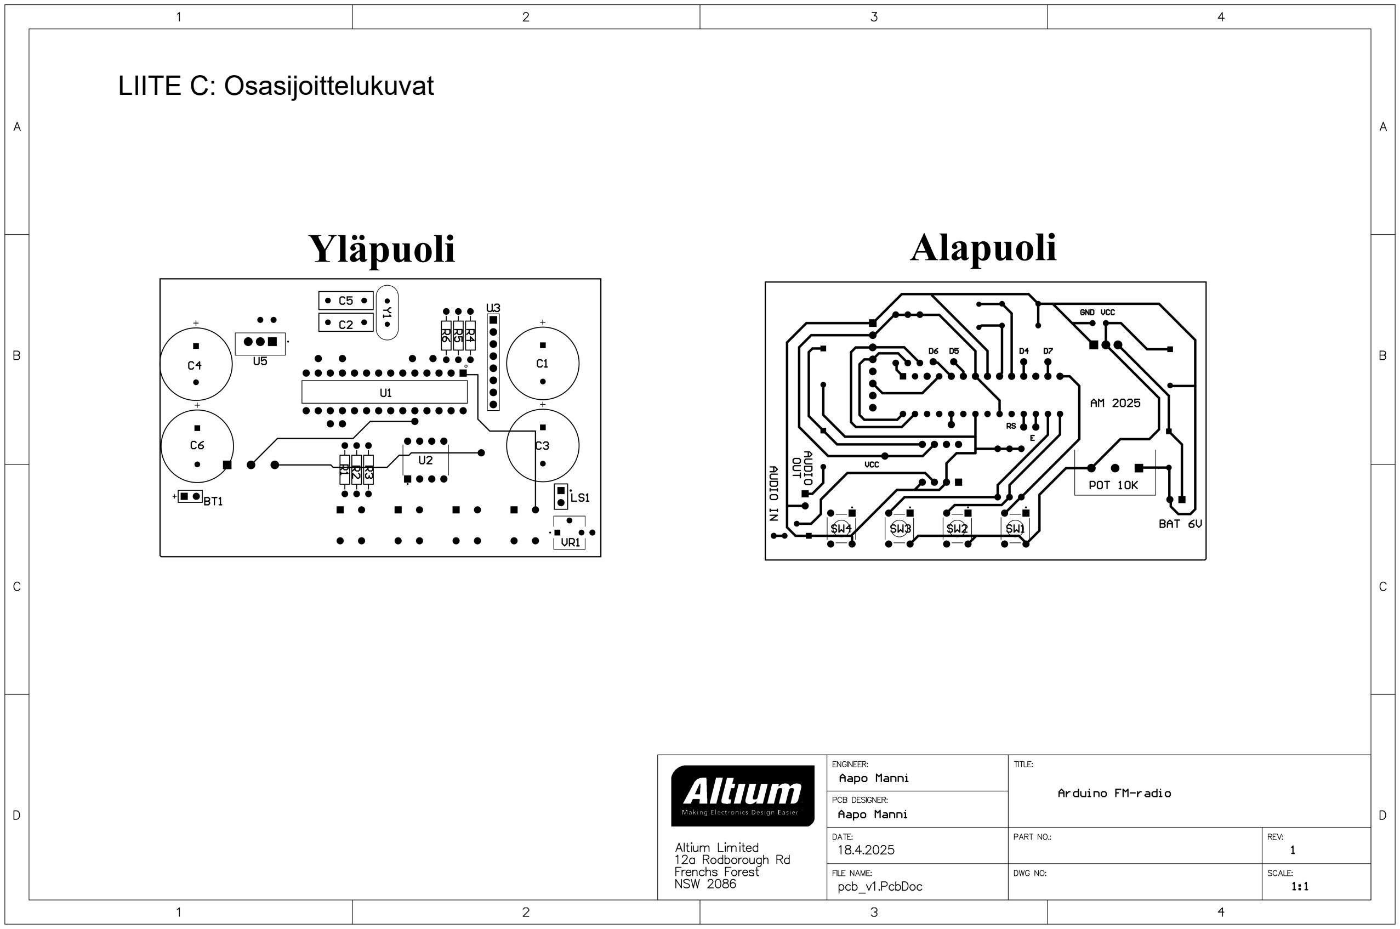
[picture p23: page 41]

Yläpuoli | Alapuoli

1 #include <LiquidCrystal.h> 2 #include <Si4703_Breakout.h> 3 #include <Wire.h>
4
5 //Aapo Manni 2025
6 //Arduino-pohjainen koodi Si4703-kehitysalustan ohjaamiseen. 7
8 int resetPinni = 2;
9 int SDIO = A4;
10 int SCLK = A5;
11
12 Si4703_Breakout radio(resetPinni, SDIO, SCLK);

### 13 int kanava = 937; //aloituskanava

14 int volume;
15
16 //Kytkimiä vastaavien pinnien määritys 17 const int seek_up_pinni = 8;
18 const int seek_down_pinni = 9;
19 const int fine_tune_pinni = 10;
20
21
22 //Pinnien määritys LCD:tä varten.
23 const int rs = 12, en = 11, d4 = 5, d5 = 4, d6 = 3, d7 = 7; 24 LiquidCrystal lcd(rs, en, d4, d5, d6, d7);
25
26

### 27 void setup()

28 {
29 //Si4703 alustus
30 radio.powerOn();
31
32 //Aloituskanavan asettaminen 33 radio.setChannel(937);
34
35 //LCD:n alustus
36 lcd.begin(16,2);
37
38 }
39
40
41 //Palauttaa kokonaisluvun välillä 0-15 riippuen siitä mille 42 //tasolle äänenvoimakkuus halutaan asettaa

### 43 int lue_volume(){

44
45 //Lukee potentiometrin arvon.
46 int vol = analogRead(A1); 47
48 //Skaalaa luvun välille 0-15.
49 volume = (vol-22)/61.5;
50
51 //Määrittää suurimmaksi arvoksi 15.

### 52 if (volume >= 16){

53 volume = 15;
54 }
55
56 //Asettaa radion äänenvoimakkuuden 57 radio.setVolume(volume);
58 }
59
60
61 //Pääfunktio

### 62 void loop()

63 {
64 //Lukee potentiometrin arvon ja asettaa äänenvoimakkuuden 65 lue_volume();
66
67 //Odottaa, että SEEK UP-nappia painetaan

### 68 if (digitalRead(8)){

69 kanava = radio.seekUp();
70 }
71
72 //Odottaa, että SEEK DOWN-nappia painetaan

### 73 if (digitalRead(9)){

# LIITE D: Ohjelmakoodi

74 kanava = radio.seekDown();
75 }
76
77 //Odottaa, että FINE TUNE-nappia painetaan

### 78 if (digitalRead(10)){

79 kanava = kanava+1;
80 radio.setChannel(kanava);
81 }
82
83 //Rajaa taajuudet välille 87,5-108 MHz

### 84 if (kanava == 0){

85 kanava = 875;
86 }
87
88 //Päivittää LCD-näytön arvon
89 naytto();
90
91 //200 ms viive toiminnan varmistamiseksi 92 delay(200);
93 }
94
95 //Tämä funktio päivittää LCD-näytön tietoja.

### 96 void naytto()

97 {
98 //Muuntaa kanavan arvon desimaaliksi. Esim. 937 -> 93.7
99 float desimaali = kanava / 10.0;
100
101 //Asettaa soitettavan taajuuden LCD:n ensimmäiselle riville. 102 lcd.setCursor(0, 0);
103 lcd.print("FREQ: ");
104 lcd.print(desimaali, 1);
105 lcd.print(" MHz ");
106
107 //Asettaa äänenvoimakkuuden toiselle LCD:n riville. 108 lcd.setCursor(0, 1);
109 lcd.print("VOLUME: ");
110
111
112 //Jos äänenvoimakkuus saavuttaa maksimin se tulostetaan MAX LCD:lle. 113 if (volume == 15){
114 lcd.print("MAX");
115 return;
116 }
117
118 //Jos äänenvoimakkuus saavuttaa minimin se tulostetaan MIN LCD:lle. 119 if (volume == 0){
120 lcd.print("MIN");
121 return;
122 }
123
124 // Muissa tilanteissa tulostetaan äänenvoimakkuus numeroarvona. 125 lcd.print(volume);
126 | lcd.print(" | ");
127
128 }
129

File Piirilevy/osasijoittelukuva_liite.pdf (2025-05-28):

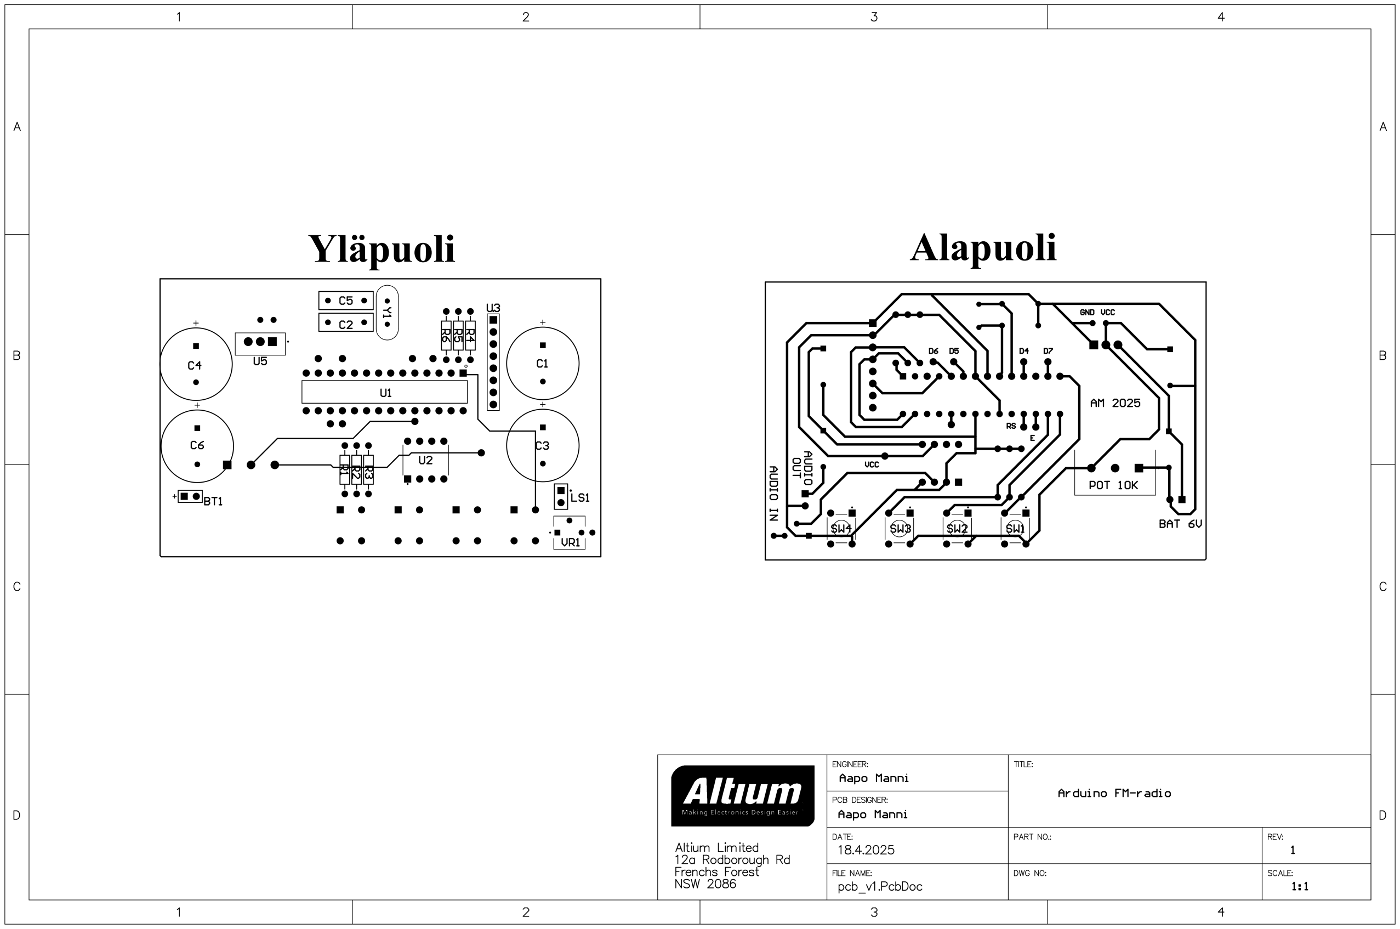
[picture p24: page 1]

Yläpuoli | Alapuoli

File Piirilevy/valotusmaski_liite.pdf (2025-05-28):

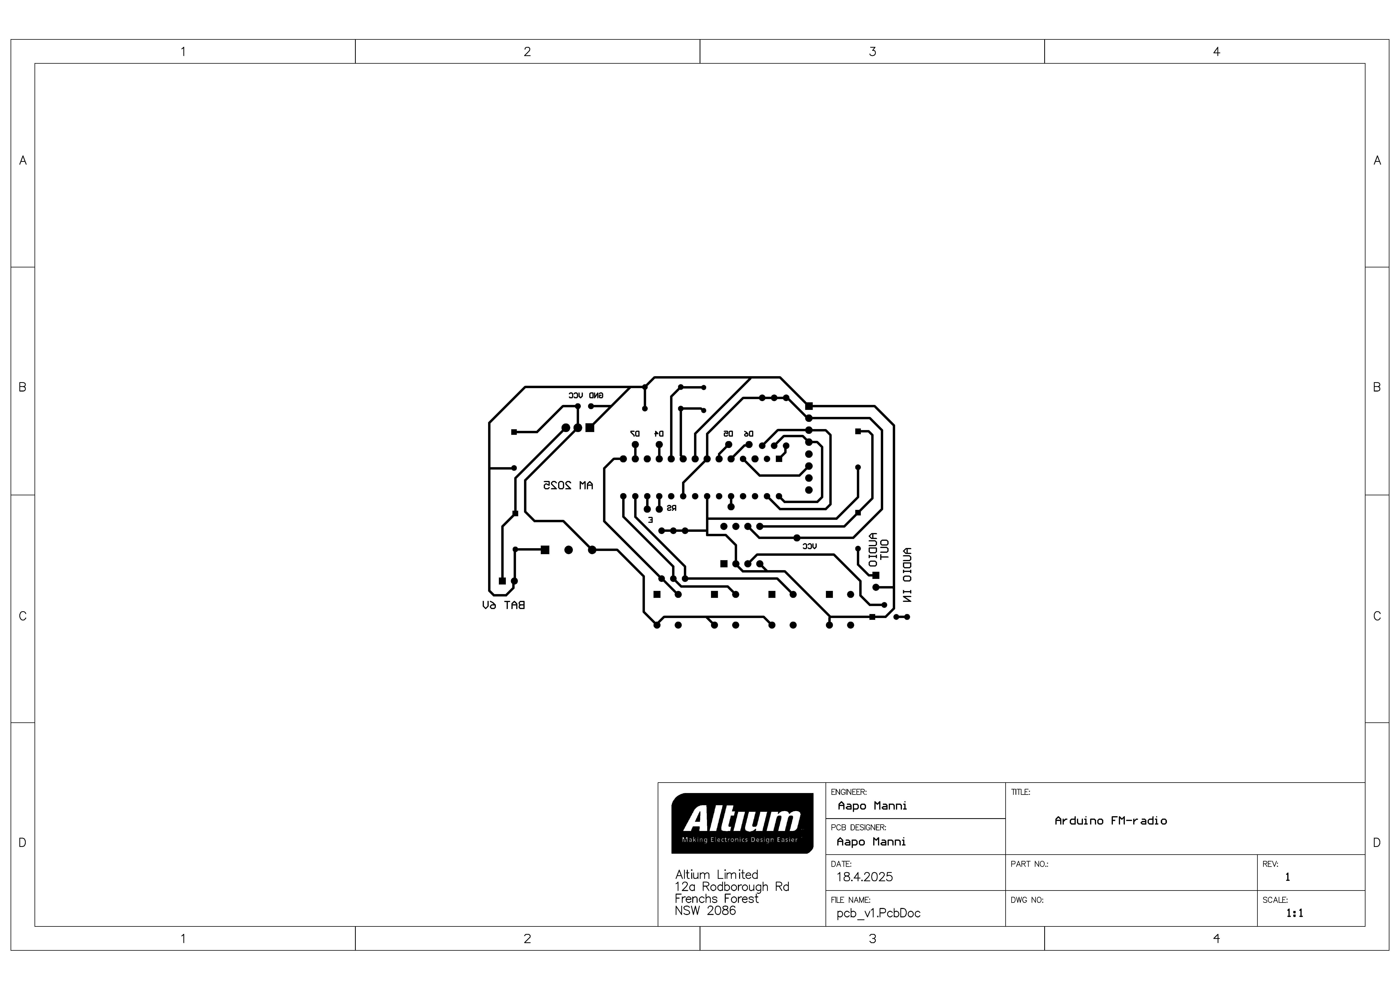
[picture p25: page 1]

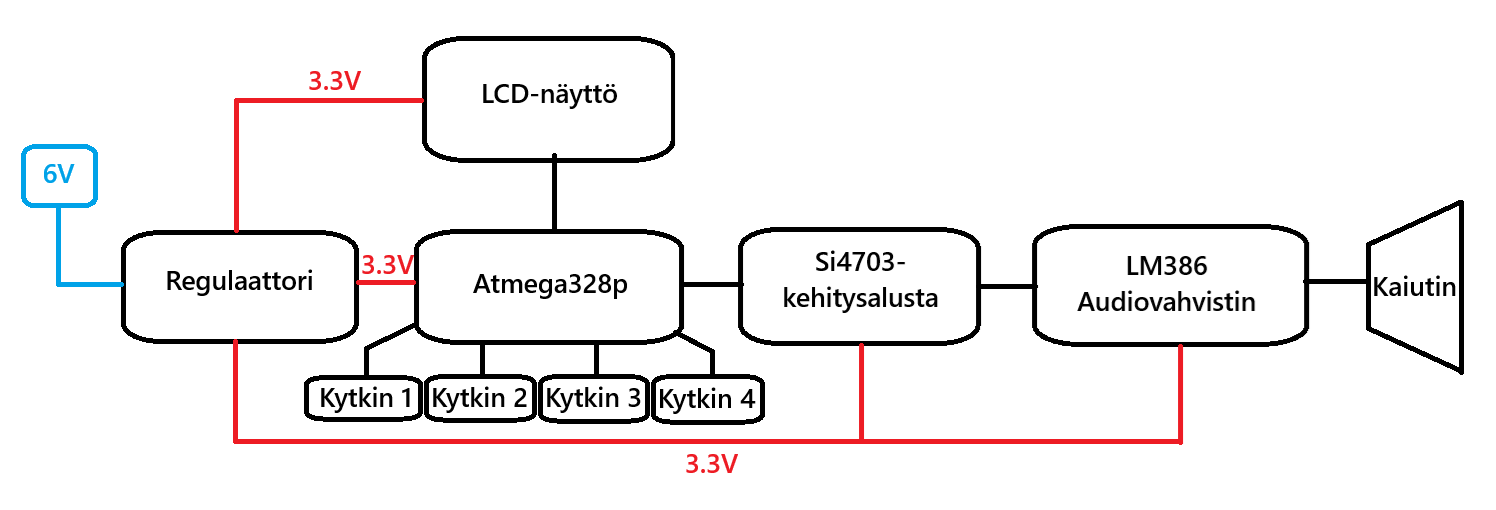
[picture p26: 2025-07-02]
Lohkokaavio.png

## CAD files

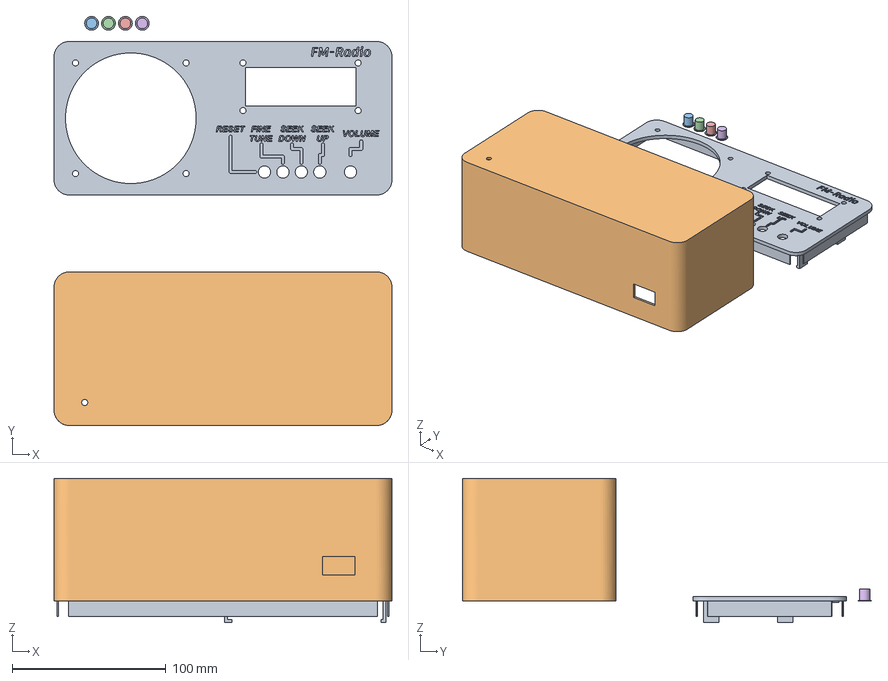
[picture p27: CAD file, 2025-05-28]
3D-tulostus/kansi + pohja.3mf
220.0 x 266.3 x 94.0 mm

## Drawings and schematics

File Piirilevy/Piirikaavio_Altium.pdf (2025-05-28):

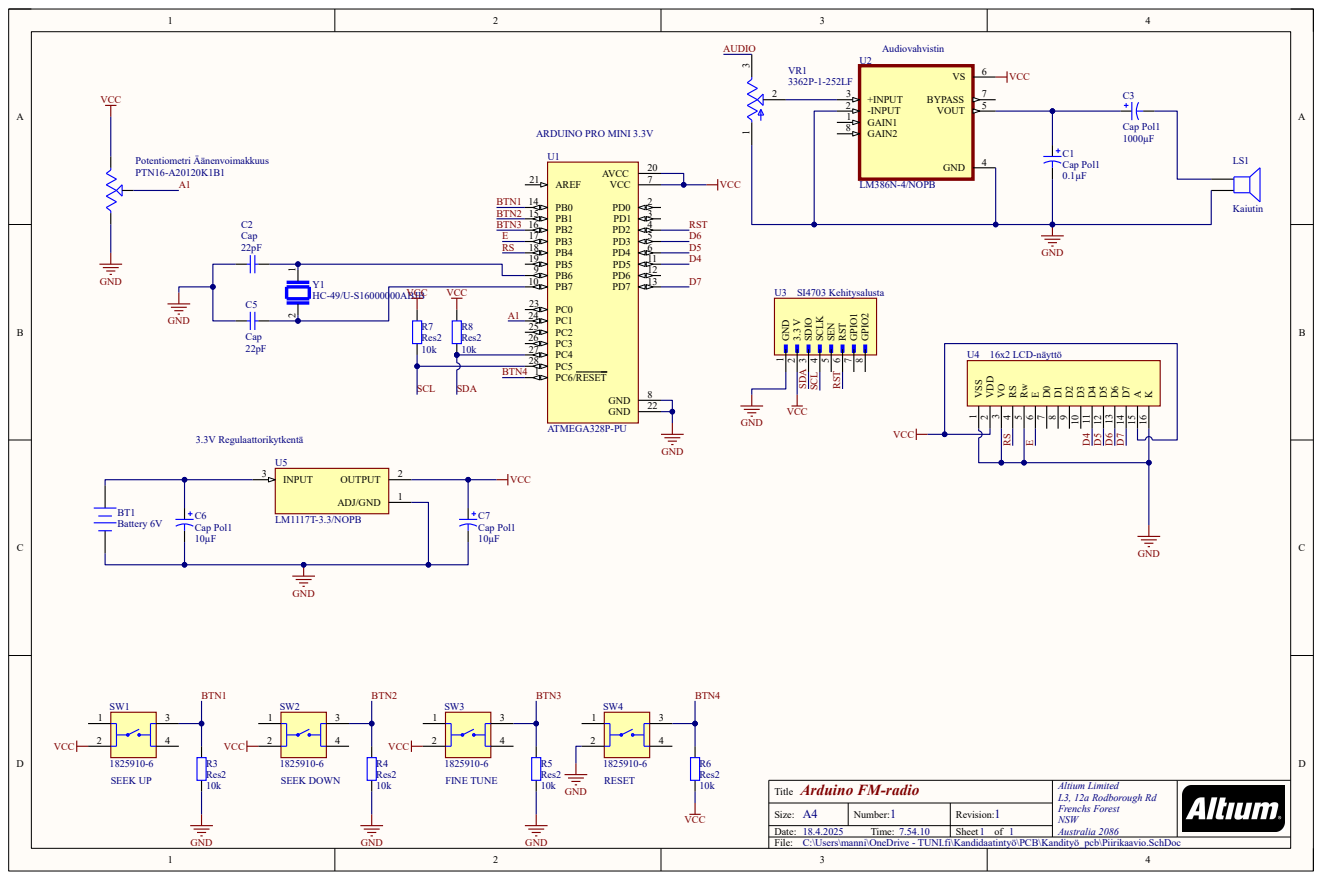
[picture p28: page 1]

Arduino FM-radio
Title
C:\Users\manni\OneDrive - TUNI.fi\Kandidaatintyö\PCB\Kandityö_pcb\Piirikaavio.SchDoc

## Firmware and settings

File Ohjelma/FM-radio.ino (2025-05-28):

#include <LiquidCrystal.h>
#include <Si4703_Breakout.h>
#include <Wire.h>

//Aapo Manni 2025
//Arduino-pohjainen koodi Si4703-kehitysalustan ohjaamiseen.

int resetPinni = 2;
int SDIO = A4;
int SCLK = A5;

Si4703_Breakout radio(resetPinni, SDIO, SCLK);
int kanava = 937; //aloituskanava
int volume;

//Kytkimiä vastaavien pinnien määritys
const int seek_up_pinni = 8;
const int seek_down_pinni = 9;
const int fine_tune_pinni = 10;


//Pinnien määritys LCD:tä varten.
const int rs = 12, en = 11, d4 = 5, d5 = 4, d6 = 3, d7 = 7;
LiquidCrystal lcd(rs, en, d4, d5, d6, d7);


void setup()
{
  //Si4703 alustus
  radio.powerOn();
  
  //Aloituskanavan asettaminen
  radio.setChannel(937);
  
  //LCD:n alustus
  lcd.begin(16,2);  
  
}


//Palauttaa kokonaisluvun välillä 0-15 riippuen siitä mille
//tasolle äänenvoimakkuus halutaan asettaa
int lue_volume(){
  
  //Lukee potentiometrin arvon.
  int vol = analogRead(A1);

  //Skaalaa luvun välille 0-15.
  volume = (vol-22)/61.5;

  //Määrittää suurimmaksi arvoksi 15.
  if (volume >= 16){
    volume = 15;
  }
  
  //Asettaa radion äänenvoimakkuuden
  radio.setVolume(volume);
  }


//Pääfunktio
void loop()
{
  //Lukee potentiometrin arvon ja asettaa äänenvoimakkuuden
  lue_volume(); 
  
  //Odottaa, että SEEK UP-nappia painetaan
  if (digitalRead(8)){
    kanava = radio.seekUp();    
  }
  
  //Odottaa, että SEEK DOWN-nappia painetaan
  if (digitalRead(9)){
    kanava = radio.seekDown();    
  }

  //Odottaa, että FINE TUNE-nappia painetaan
  if (digitalRead(10)){
    kanava = kanava+1;
    radio.setChannel(kanava);    
  }  

  //Rajaa taajuudet välille 87,5-108 MHz
  if (kanava == 0){
    kanava = 875;
  }

  //Päivittää LCD-näytön arvon
  naytto(); 

  //200 ms viive toiminnan varmistamiseksi
  delay(200);    
}

//Tämä funktio päivittää LCD-näytön tietoja.
void naytto()
{
  //Muuntaa kanavan arvon desimaaliksi. Esim. 937 -> 93.7
  float desimaali = kanava / 10.0; 
  
  //Asettaa soitettavan taajuuden LCD:n ensimmäiselle riville.
  lcd.setCursor(0, 0); 
  lcd.print("FREQ: "); 
  lcd.print(desimaali, 1);
  lcd.print(" MHz "); 
  
  //Asettaa äänenvoimakkuuden toiselle LCD:n riville.
  lcd.setCursor(0, 1);
  lcd.print("VOLUME: ");  


  //Jos äänenvoimakkuus saavuttaa maksimin se tulostetaan MAX LCD:lle.
  if (volume == 15){
    lcd.print("MAX");
    return;
  }

  //Jos äänenvoimakkuus saavuttaa minimin se tulostetaan MIN LCD:lle.
  if (volume == 0){
    lcd.print("MIN");
    return;
  }

  // Muissa tilanteissa tulostetaan äänenvoimakkuus numeroarvona.
  lcd.print(volume);
  lcd.print("   ");
     
}

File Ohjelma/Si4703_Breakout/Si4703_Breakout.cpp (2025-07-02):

/*

	2/11/13 - Fixed for Arduino 1.0. Changed wire.send and wire.receive to wire.write and wire.read. Also added arduino.h and removed wprogram.h

*/

#include "Arduino.h"
#include "Si4703_Breakout.h"
#include "Wire.h"

Si4703_Breakout::Si4703_Breakout(int resetPin, int sdioPin, int sclkPin)
{
  _resetPin = resetPin;
  _sdioPin = sdioPin;
  _sclkPin = sclkPin;
}

void Si4703_Breakout::powerOn()
{
    si4703_init();
}

void Si4703_Breakout::setChannel(int channel)
{
  //Freq(MHz) = 0.200(in USA) * Channel + 87.5MHz
  //97.3 = 0.2 * Chan + 87.5
  //9.8 / 0.2 = 49
  int newChannel = channel * 10; //973 * 10 = 9730
  newChannel -= 8750; //9730 - 8750 = 980
  newChannel /= 10; //980 / 10 = 98

  //These steps come from AN230 page 20 rev 0.5
  readRegisters();
  si4703_registers[CHANNEL] &= 0xFE00; //Clear out the channel bits
  si4703_registers[CHANNEL] |= newChannel; //Mask in the new channel
  si4703_registers[CHANNEL] |= (1<<TUNE); //Set the TUNE bit to start
  updateRegisters();

  //delay(60); //Wait 60ms - you can use or skip this delay

  //Poll to see if STC is set
  while(1) {
    readRegisters();
    if( (si4703_registers[STATUSRSSI] & (1<<STC)) != 0) break; //Tuning complete!
  }

  readRegisters();
  si4703_registers[CHANNEL] &= ~(1<<TUNE); //Clear the tune after a tune has completed
  updateRegisters();

  //Wait for the si4703 to clear the STC as well
  while(1) {
    readRegisters();
    if( (si4703_registers[STATUSRSSI] & (1<<STC)) == 0) break; //Tuning complete!
  }
}

int Si4703_Breakout::seekUp()
{
	return seek(SEEK_UP);
}

int Si4703_Breakout::seekDown()
{
	return seek(SEEK_DOWN);
}

void Si4703_Breakout::setVolume(int volume)
{
  readRegisters(); //Read the current register set
  if(volume < 0) volume = 0;
  if (volume > 15) volume = 15;
  si4703_registers[SYSCONFIG2] &= 0xFFF0; //Clear volume bits
  si4703_registers[SYSCONFIG2] |= volume; //Set new volume
  updateRegisters(); //Update
}


void Si4703_Breakout::readRDS(char* buffer, long timeout)
{ 	
	long endTime = millis() + timeout;
  boolean completed[] = {false, false, false, false};
  int completedCount = 0;
  while(completedCount < 4 && millis() < endTime) {
	readRegisters();
	if(si4703_registers[STATUSRSSI] & (1<<RDSR)){
		// ls 2 bits of B determine the 4 letter pairs
		// once we have a full set return
		// if you get nothing after 20 readings return with empty string
	  uint16_t b = si4703_registers[RDSB];
	  int index = b & 0x03;
	  if (! completed[index] && b < 500)
	  {
		completed[index] = true;
		completedCount ++;
	  	char Dh = (si4703_registers[RDSD] & 0xFF00) >> 8;
      	char Dl = (si4703_registers[RDSD] & 0x00FF);
		buffer[index * 2] = Dh;
		buffer[index * 2 +1] = Dl;
		 
		 //Serial.print(si4703_registers[RDSD]); Serial.print(" ");
		 //Serial.print(index);Serial.print(" ");
		 //Serial.write(Dh);
		 //Serial.write(Dl);
		 //Serial.println();
      }
      delay(30); //Wait for the RDS bit to clear
	}
	else {
	  delay(40); //From AN230, using the polling method 40ms should be sufficient amount of time between checks
	}
  }
	if (millis() >= endTime) {
		buffer[0] ='\0';
		return;
	}

  buffer[8] = '\0';
}




//To get the Si4703 inito 2-wire mode, SEN needs to be high and SDIO needs to be low after a reset
//The breakout board has SEN pulled high, but also has SDIO pulled high. Therefore, after a normal power up
//The Si4703 will be in an unknown state. RST must be controlled
void Si4703_Breakout::si4703_init() 
{
  pinMode(_resetPin, OUTPUT);
  pinMode(_sdioPin, OUTPUT); //SDIO is connected to A4 for I2C
  digitalWrite(_sdioPin, LOW); //A low SDIO indicates a 2-wire interface
  digitalWrite(_resetPin, LOW); //Put Si4703 into reset
  delay(1); //Some delays while we allow pins to settle
  digitalWrite(_resetPin, HIGH); //Bring Si4703 out of reset with SDIO set to low and SEN pulled high with on-board resistor
  delay(1); //Allow Si4703 to come out of reset

  Wire.begin(); //Now that the unit is reset and I2C inteface mode, we need to begin I2C

  readRegisters(); //Read the current register set
  //si4703_registers[0x07] = 0xBC04; //Enable the oscillator, from AN230 page 9, rev 0.5 (DOES NOT WORK, wtf Silicon Labs datasheet?)
  si4703_registers[0x07] = 0x8100; //Enable the oscillator, from AN230 page 9, rev 0.61 (works)
  updateRegisters(); //Update

  delay(500); //Wait for clock to settle - from AN230 page 9

  readRegisters(); //Read the current register set
  si4703_registers[POWERCFG] = 0x6001; //Enable the IC + MONO!!
  //  si4703_registers[POWERCFG] |= (1<<SMUTE) | (1<<DMUTE); //Disable Mute, disable softmute
  //si4703_registers[SYSCONFIG1] |= (1<<RDS); //Enable RDS
  si4703_registers[SYSCONFIG1] |= (1<<RDS); //Enable RDS 
  //si4703_registers[SYSCONFIG1] |= (1<<DE); //50kHz Europe setup
  si4703_registers[SYSCONFIG2] |= (1<<SPACE0); //100kHz channel spacing for Europe

  si4703_registers[SYSCONFIG2] &= 0xFFF0; //Clear volume bits
  si4703_registers[SYSCONFIG2] |= 0x0001; //Set volume to lowest
  updateRegisters(); //Update

  delay(110); //Max powerup time, from datasheet page 13
}

//Read the entire register control set from 0x00 to 0x0F
void Si4703_Breakout::readRegisters(){

  //Si4703 begins reading from register upper register of 0x0A and reads to 0x0F, then loops to 0x00.
  Wire.requestFrom(SI4703, 32); //We want to read the entire register set from 0x0A to 0x09 = 32 bytes.

  while(Wire.available() < 32) ; //Wait for 16 words/32 bytes to come back from slave I2C device
  //We may want some time-out error here

  //Remember, register 0x0A comes in first so we have to shuffle the array around a bit
  for(int x = 0x0A ; ; x++) { //Read in these 32 bytes
    if(x == 0x10) x = 0; //Loop back to zero
    si4703_registers[x] = Wire.read() << 8;
    si4703_registers[x] |= Wire.read();
    if(x == 0x09) break; //We're done!
  }
}

//Write the current 9 control registers (0x02 to 0x07) to the Si4703
//It's a little weird, you don't write an I2C addres
//The Si4703 assumes you are writing to 0x02 first, then increments
byte Si4703_Breakout::updateRegisters() {

  Wire.beginTransmission(SI4703);
  //A write command automatically begins with register 0x02 so no need to send a write-to address
  //First we send the 0x02 to 0x07 control registers
  //In general, we should not write to registers 0x08 and 0x09
  for(int regSpot = 0x02 ; regSpot < 0x08 ; regSpot++) {
    byte high_byte = si4703_registers[regSpot] >> 8;
    byte low_byte = si4703_registers[regSpot] & 0x00FF;

    Wire.write(high_byte); //Upper 8 bits
    Wire.write(low_byte); //Lower 8 bits
  }

  //End this transmission
  byte ack = Wire.endTransmission();
  if(ack != 0) { //We have a problem! 
    return(FAIL);
  }

  return(SUCCESS);
}
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
